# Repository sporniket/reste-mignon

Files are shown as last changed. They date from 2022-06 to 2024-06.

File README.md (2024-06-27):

# Sporniket's 'ReSTe mignon'

> [WARNING] Please read carefully this note before using this project. It contains important facts.

Content

1. What is **Sporniket's 'ReSTe mignon'**, and when to use it ?
2. What should you know before using **Sporniket's 'ReSTe mignon'** ?
3. How to use **Sporniket's 'ReSTe mignon'** ?
4. Known issues
5. Miscellanous

## 1. What is **Sporniket's 'ReSTe mignon'**, and when to use it ?

**Sporniket's 'ReSTe mignon'** is a _RE_-make of the computer known as 'Atari _STe_', on a B5-sized (250×175 mm) PCB. Smaller, so 'cute', hence '_mignon_'.

This is a project made with [Kicad](https://www.kicad.org/). I started this work [from the conversion of the original Atari STe schematics](https://github.com/sporniket/kicad-conversions--atari-ste-motherboard--c300780-001).

### Licence

**Sporniket's 'ReSTe mignon'** is marked with CC0 1.0 Universal. To view a copy of this license, visit http://creativecommons.org/publicdomain/zero/1.0

**Sporniket's 'ReSTe mignon'** is distributed in the hope that it will be useful, but WITHOUT ANY WARRANTY; without even the implied warranty of MERCHANTABILITY or FITNESS FOR A PARTICULAR PURPOSE.

### Releases notes

#### extension-cpu-68k-plcc68--v1.0.0-beta.1

First beta implemantion of the extension board holding the CPU in a PLCC68 package. This implements the [extension port for CPU and Blitter](README-extension-port-cpu-and-blitter.md)

#### mk0-0.1-schematic / 2022-06-08

The first complete schematics of the mark0 milestone, starting [from the conversion of the original Atari STe schematics](https://github.com/sporniket/kicad-conversions--atari-ste-motherboard--c300780-001).

  * Added DIP-64 CPU port extension
  * Removed T-filters
  * Deleted circuitry related to PAL/NTSC and modulator
  * Resolves #1 : Use 4-resistor packs wherever it is possible
  * Resolves #2 : apply the pull-up fix to data and address bus
  * Resolves #3 : Apply the DMA Pull up fix on databus
  * Resolves #4 : Apply the 1772 pull-up fix
  * Resolves #6 : Apply the reset fix
  * Resolves #5 : Apply the fix for the video ghosting
  * Resolves #7 : Assign SMD footprints to resistors pack
  * Resolves #8 : Assign 1206 hand-solder footprints to non polarized capacitors
  * Resolves #9 : Assign radial THT footprints to polarized capacitors
  * Resolves #10 : Remove the C103
  * Resolves #11 : Use the reference 'FB?' for the ferrite beads
  * Resolves #12 : Use the reference 'CP?' for polarized capacitors
  * Resolves #13 : assign 1206 hand-solder footprints to resistors
  * Resolves #14 : assign smd footprints for ferrite beads
  * Resolves #15 : assign smd footprints to the inductors
  * Resolves #16 : assign smd footprints to diodes
  * Resolves #17 : assign smd footprints to transistors
  * Resolves #18 : Apply the LMC mixer fix
  * Fixes #19 : Reinstate the external blitter for the mark 0 version
  * Resolves #20 : Replace polarized capacitors CP101 and CP536 by unpolarized ones
  * Resolves #21 : Change Q400 to Q405 from 2N3904 to MMBT3904
  * Resolves #22 : Change Q500 from LM78L82 to UA78L08 -- add bypass capacitor on input
  * Resolves #23 : Add internal ACSI port
  * Resolves #24 : Add an internal port to make easier to plug a RGB2HDMI
  * Fixes #28 : [BUG] Incomplete restoration of the blitter

## 2. What should you know before using **Sporniket's 'ReSTe mignon'** ?

**Sporniket's 'ReSTe mignon'** is made using [Kicad](https://www.kicad.org/).

The git repository use several submodules that one has to fetch in order to get the symbols, footprint and 3dmodels. One submodule requires [python3](https://www.python.org) and [GNU make](https://www.gnu.org/software/make/) to generate the libraries of symbols for integrated circuits.

> Do not use **Sporniket's 'ReSTe mignon'** if this project is not suitable for your project.

## 3. How to use **Sporniket's 'ReSTe mignon'** ?

### From sources

To get the latest available models, one must clone the git repository **and the submodules**. Then some modules needs a build step to generate its libraries.

	git clone --recurse-submodules https://github.com/sporniket/reste-mignon.git
	cd reste-mignon/kicad-symbols-generated
	make

Then, open the project in Kicad.

### From github releases

A github **schematic only** release (with `schematics` in the release tag and name) will provide a PDF of the schematics

A github **regular** release will provide :

* A standalone Kicad project (all custom libraries included and ready to use)
* A PDF of the schematics
* A PDF of the silkscreen
* If applicable, a Gerber for boardmanufacturer. Some details may have been adapted for a specific manufacturer.
* If applicable, a BOM, and pick an place files, likely for a specific manufacturer too.

## 4. Known issues
See the [project issues](https://github.com/sporniket/reste-mignon/issues) page.

## 5. Miscellanous

### Report issues
Use the [project issues](https://github.com/sporniket/reste-mignon/issues) page.

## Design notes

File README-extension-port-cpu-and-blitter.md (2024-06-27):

# Extension port for the CPU and Blitter

## Context

In order to reach the target dimension (given _surface_), it will be acceptable to _stack_ elements vertically.

The following specifications define an extension port that will allow to stack the CPU, and the blitter for setups that require it (namely, with a MCU without integrated blitter). Both will be stacked over the MCU.

## Physical layout

The overall goal is to have : 

* The biggest square with an side length rounded to 50 mils, that fits a 10×10cm square.
* Two head 100mils pitched header connectors, each 2 rows of different number of contacts, vertically oriented, put on a diagonally opposite corners of the square. 
  * **Connector A** will be on the north of the west side.
  * **Connector B** will be on the south of the east side. 
  * When one card is plugged on the main board or another card, the connector casing are flush with the borders
  
Which gives : 

* A square with a side of 3900mils/99.06mm
* From the North-West corner, pin #1 of connector A will be at coordinate (50,50) mils
* From pin #1 of connector A, pin #1 of connector B will be at coordinate (3700, 2300) mils

On the mainboard, the GST MCU will be oriented 90° clock-side, in other words, the GST MCU's North (pin #1 to the north-west) points toward the East of the extension port.

On the blitter extension, the North of the blitter (pin #1 to the north)  will points toward the South of the extension port.

On the PLCC CPU extension, the North of the CPU (pin #1 to the north) will points toward the East of the extension port.

On the DIP CPU extension, the North of the CPU (great axes of the DIP chip along North/South, pin #1 to the north) will points toward the North of the extension port

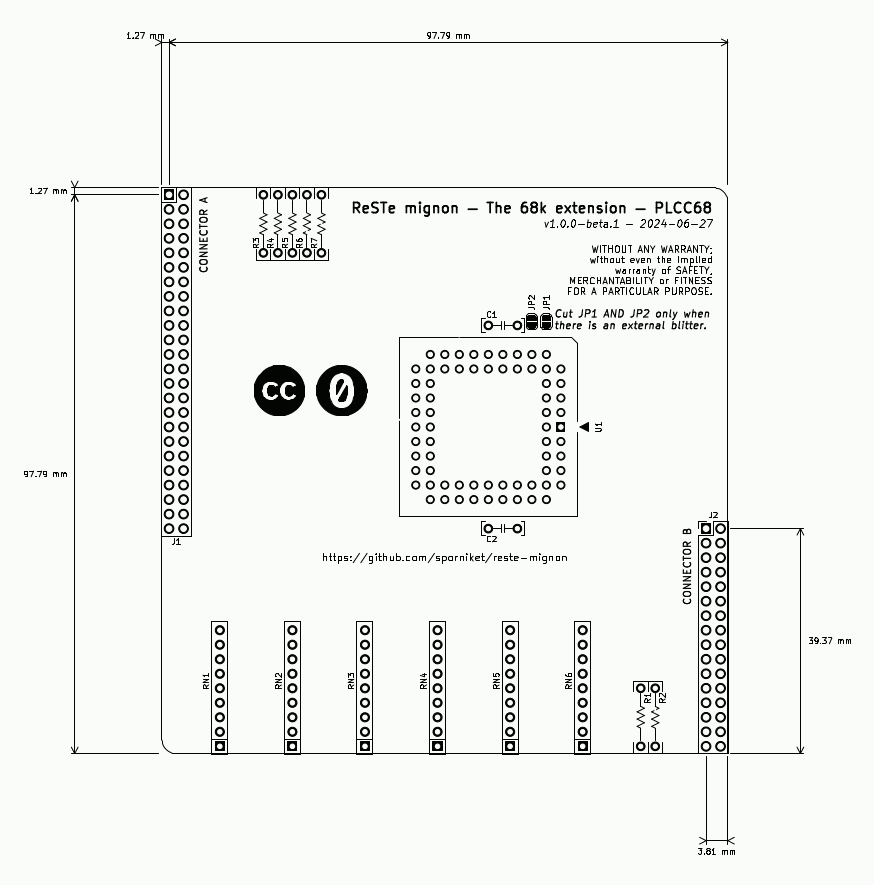
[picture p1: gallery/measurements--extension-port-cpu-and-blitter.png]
An actual extension pcb as a map of the extension port with measurements


## Connector specifications

The following pin assignments have been devised to minimize routing to the MCU, hopefully.

Pin numbers are assigned as follow :

* Connector seen from above, vertically oriented : the two rows are vertical, columns are horizontal.
* From left to right, columns by columns

Signals named prefixed by `BLT.` should target the blitter. Signals prefixed by `68.` should target the CPU.

### Connector A

| Pin | Signal | | Pin | Signal |
|---|---|---|---|---|
|1|`GND`| |2|`CLK`|
|3|`BERR`| |4|`GND`|
|5|`VPA`| |6|`VMA`|
|7|`BLT.BG`| |8|`BLT.BGACK`|
|9|`GND`| |10|`BR`|
|11|`IPL1`| |12|`IPL0`|
|13|`FC2`| |14|`IPL2`|
|15|`FC1`| |16|`GND`|
|17|`A23`| |18|`FC0`|
|19|`A21`| |20|`A22`|
|21|`GND`| |22|`A20`|
|23|`A18`| |24|`A19`|
|25|`A16`| |26|`A17`|
|27|`A15`| |28|`GND`|
|29|`A13`| |30|`A14`|
|31|`A11`| |32|`A12`|
|33|`GND`| |34|`A10`|
|35|`A8`| |36|`A9`|
|37|`A6`| |38|`A7`|
|39|`BLT.INT`| |40|`GND`|
|41|`A4`| |42|`A5`|
|43|`A2`| |44|`A3`|
|45|`GND`| |46|`A1`|
|47|`E`| |48|`GND`|

### Connector B

| Pin | Signal | | Pin | Signal |
|---|---|---|---|---|
|1|`D1`| |2|`D0`|
|3|`D2`| |4|`GND`|
|5|`D4`| |6|`D3`|
|7|`D6`| |8|`D5`|
|9|`GND`| |10|`D7`|
|11|`D9`| |12|`D8`|
|13|`D11`| |14|`D10`|
|15|`D12`| |16|`GND`|
|17|`D14`| |18|`D13`|
|19|`DTACK`| |20|`D15`|
|21|`GND`| |22|`R/W`|
|23|`UDS`| |24|`LDS`|
|25|`RESET`| |26|`AS`|
|27|`HALT`| |28|`GND`|
|29|`68.BG`| |30|`68.BGACK`|
|31|`VCC`| |32|`VCC`|

## Usages

### Main board

The extension port is placed around the GST MCU, so that the GST MCU will be oriented 90° clock-side, in other words, the GST MCU's North (pin #1 to the north-west) points toward the East of the extension port.

All the signal from the extension port, except `68.BGACK` and `68.BG` (connector B, pins #29 and #30), are wired to the MCU.

### Blitter extension

The extension port is placed around the blitter, so that the North of the blitter (pin #1 to the north)  will points toward the South of the extension port.

All relevant signals are wired to the blitter, espectially `68.BGACK` and `68.BG` (connector B, pins #29 and #30).

### CPU PLCC extension 

The extension port is placed around the PLCC CPU, so that the North of the CPU (pin #1 to the north) will points toward the East of the extension port.

All relevant signals are wired to the blitter, espectially `68.BGACK` and `68.BG` (connector B, pins #29 and #30).

A configuration system (jumpers, solder blobs, etc...) allows to connect to `BLT.BG` and `BLT.BGACK` (connector A, pins #7 and #8) in addition to `68.BGACK` and `68.BG`.

The CPU extension also implement the pull-ups on the various relevant signals.

### CPU DIP extension

The extension port is placed around the DIP CPU, so that the North of the CPU (great axes of the DIP chip along North/South, pin #1 to the north) will points toward the North of the extension port.

All relevant signals are wired to the blitter, espectially `68.BGACK` and `68.BG` (connector B, pins #29 and #30).

A configuration system (jumpers, solder blobs, etc...) allow to connect to `BLT.BG` and `BLT.BGACK` (connector A, pins #7 and #8) in addition to `68.BGACK` and `68.BG`.

The CPU extension also implement the pull-ups on the various relevant signals.

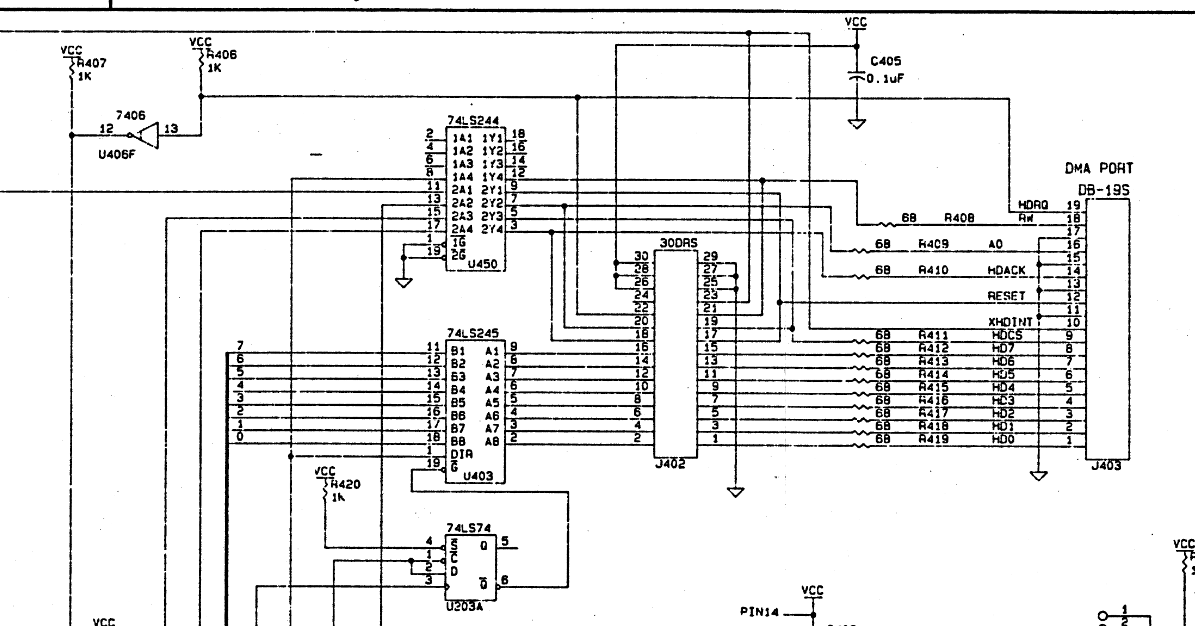
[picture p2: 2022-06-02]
references/MEGA_STE__ACSI_internal_connector.png

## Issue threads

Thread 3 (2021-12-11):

Apply the DMA Pull up fix on databus

sporniket, 2021-12-11:
See :

* https://www.exxoshost.co.uk/forum/viewtopic.php?f=17&t=1417
* https://www.exxoshost.co.uk/forum/viewtopic.php?f=23&t=1546&p=17513#p17513

Closed 2022-02-09.

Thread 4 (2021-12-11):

Apply the 1772 pull-up fix

sporniket, 2021-12-11:
See https://www.exxoshost.co.uk/forum/viewtopic.php?f=17&t=1395

sporniket, 2022-02-09:
Maybe leave this one to an optionnal board, as it depends off the drive actually connected ?

sporniket, 2022-02-10:
I will assume that there are more non-Atari drive than original drives, hence more probably needed.

Closed 2022-02-10.

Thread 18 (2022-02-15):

Apply the LMC mixer fix

sporniket, 2022-02-15:
See original description : http://atari.8bitchip.info/STEamFix.html

See another picture of the fix at the bottom of : https://www.exxoshost.co.uk/atari/last/STEDACFIX/index.htm

And another one in this thread : https://www.exxoshost.co.uk/forum/viewtopic.php?f=29&t=5119#p79553

Closed 2022-02-15.

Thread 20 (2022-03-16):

Replace polarized capacitors CP101 and CP536 by unpolarized ones

sporniket, 2022-03-16:
CP101 is 0.01uF ; CP536 is 0.1uF ; small enough to be replaced by MLCC capacitors.

CP101 &rarr; C101, assigned MLCC 1206 footprint
CP536 &rarr; C536, assigned MLCC 1206 footprint

Closed 2022-03-16.

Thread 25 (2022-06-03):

Add a video VGA port with a switch between color/monochrome mode

sporniket, 2022-06-03:
The VGA will route the analog video signal.

To switch between mono/rgb mode, a triple analog 2:1 mux is required, like SN74LV4053A. 4 trimpot are also require to setup the appropriate level/impedance for the vga monitor (to be checked).

Something along that :

* Red &rarr; trimpot_red &rarr; mux_1_a
* Green &rarr; trimpot_green &rarr; mux_2_a
* Blue &rarr; trimpot_blue &rarr; mux_3_a
* Mono &rarr; trimpot_mono &rarr; mux_1_b + mux_2_b + mux_3_b
* GND &rarr; switch &rarr; mux_ab_sel + pull_up + mono_detect **will force mono, even for the legacy connector**

sporniket, 2022-06-03:
Clearly out of scope for mark0. There is already plenty of adaptor to plug to a VGA monitor

Closed 2022-06-03.

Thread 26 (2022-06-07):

[EPIC] Allow an USB host to see the computer as an USB device

sporniket, 2022-06-07:
# Ideal Case : Serial and Parallel port

## Content

* an USB Hub IC (e.g. like the [TI TUSB2036 2 or 3 ports](https://www.ti.com/lit/ds/symlink/tusb2036.pdf))
* a power distribution IC (e.g. like the [TI TPS2044/TPS2054](https://www.ti.com/lit/ds/symlink/tps2054.pdf))
* a USB to Serial controller (WCH(Jiangsu Qin Heng) [CH340B](https://datasheet.lcsc.com/lcsc/2008191806_WCH-Jiangsu-Qin-Heng-CH340B_C81010.pdf) or [CH340T](https://datasheet.lcsc.com/lcsc/2008191806_WCH-Jiangsu-Qin-Heng-CH340T_C8689.pdf), the 'B' version needs an external 12MHz oscillator)
* a USB to Parallel port controller ([WCH(Jiangsu Qin Heng) CH340S](https://datasheet.lcsc.com/lcsc/2008191734_WCH-Jiangsu-Qin-Heng-CH340S_C109467.pdf) with external 12MHz oscillator)

The USB Hub IC and the power distribution IC are connected to the USB port (mini USB-B, or micro USB-C if unavailable, or mini USB-C if unavailable).

The '340 ICs are connected to the Hub and the power distribution ICs ; Serial is device 1, Parallel is device 2.

Level shifters are not needed

## Wiring to the ST

The pins listed are from the ST point of view. The wiring to the controllers ICs must be devised (e.g. like a [null modem](https://en.wikipedia.org/wiki/Null_modem) wiring to the Serial, and cross _busy_ and _strobe_ for Parallel)

### Serial

MC68901 :

* 8 (TX)
* 9 (RX)
* 23 (CD)
* 24 (CTS)
* 16 (RI)

YM2149

* 17 (DIR)
* 18 (RTS)

### Parallel

MC68901 :

* 22 (BUSY)

YM2149

* 6..13 (DATA[7..0], pin 6 is DATA[7], pin 13 is DATA[0])
* 16 (STROBE)

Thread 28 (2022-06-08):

[BUG] Incomplete restoration of the blitter

sporniket, 2022-06-08:
_Following #19_

* The DIP-64 socket /BG and /BGACK pins have not been reverted to `XCPUBG`/`XBGACK` resp.
* The blitter `XBGK` is pulled-up instead of `XBGACK`

Closed 2022-06-08.

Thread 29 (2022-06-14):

Redesign the reset circuit using a supervisory circuit

sporniket, 2022-06-14:
E.g. a supervisory circuit like the Microchip MPC100-450

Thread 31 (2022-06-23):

Provision mounting holes of the mother board to a chassis

sporniket, 2022-06-23:
The board targeting a B5 size (18x25 cm), there would be a grid of 3x4 = 12 mounting holes separated by around 8~9 cms

Those mounting holes will be compatible with [#6-32 UNC screws](https://en.wikipedia.org/wiki/Computer_case_screws##6-32_UNC_screw) and will be grounded

Closed 2022-07-13.

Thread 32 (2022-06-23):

Provision mounting hole for the 'dop' series of usb-c power delivery adapter

sporniket, 2022-06-23:
See

* dop-lite : https://github.com/sporniket/dop-lite /sporniket/dop-lite
* dop-regular : to do
* dop-heavy-duty : to do

Mounting holes : M2.5, like the Raspberry pi

* All the module will share the two holes around the usb port (2 holes).
* The lite module is smaller than the other one, thus will have 2 other holes that are not shared with the other units 2 other holes

&rArr; there will be 6 mounting holes. There will be enough clearance to avoid contact with metallic standoff and screws.

Closed 2022-07-13.

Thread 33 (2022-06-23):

Make the WD1772 pull-up fix optionnal

sporniket, 2022-06-23:
_Following #4_

As stated in [the initial fix description](https://exxosforum.co.uk/forum/viewtopic.php?f=17&t=1395), the fix may not be needed depending whether the actual device already has internal pull-ups or not.

Add 2 jumpers, one for the Write Data line (that require a pull-up strong enough for High Density support), and the other for the remaining lines. (see https://exxosforum.co.uk/forum/viewtopic.php?p=86993#p86993)

Closed 2022-06-23.

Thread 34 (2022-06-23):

Provision mounting holes for the Raspberry PI Zero (RGB2HDMI mod)

sporniket, 2022-06-23:
The Pi has 4 M2.5 holes

The holes will have a large clearance to avoid conduction.

Closed 2022-07-13.

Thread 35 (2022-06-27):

[mk0] allow to choose between the legacy reset circuit and a supervisory circuit

sporniket, 2022-06-27:
One could either build the legacy reset circuit, or replace it with a supervisory circuit in TO-92 package :

* Microchip MCP101-450DI/TO (push-pull output, no need for pull-up resistor)

# Microcontroller Supervisory Circuit with Push-Pull Output Active-High

> This datasheet is marked with CC0 1.0
> Universal. To view a copy of this license, visit
> http://creativecommons.org/publicdomain/zero/1.0

## Symbol

* Aliases : MCP101-D
* Reference : U
* Datasheet : https://ww1.microchip.com/downloads/aemDocuments/documents/APID/ProductDocuments/DataSheets/11187f.pdf
* Footprint : Package_TO_SOT_THT:TO-92L_Inline
* Pins layout : SIMM

## Pinout

|Pin|Name|Pin Type|Group|Comment|
|---|---|---|---|---|
|1|RST|O|OUT|Reset signal|
|2|VCC|PWR|||
|3|GND|GND|||

### Pin groups

|Group id|Rank|Comment|
|---|---|---|
|OUT|10|Output|

Closed 2022-07-13.

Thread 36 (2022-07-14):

Add a RJ11 Keyboard connector

sporniket, 2022-07-14:
To be able to connect a Mega ST(e)/TT keyboard

The filtering capacitors like in the MegaST will be added. No fuse.

Closed 2022-07-14.

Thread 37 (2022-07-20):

[mk0] Add a breakout connector for serial and parallel signal

sporniket, 2022-07-20:
> In order do experiments for #26

Make available one or two 2×X pin headers, 2.54mm pitch, connectors to have :
* Serial Rx/Tx at TTL levels &rArr; 2 signals
* Parallel data, strobe and busy &rArr; 10 signals

Either have :
* One 2×2 and one 2×10 pin headers connectors
* One 2×12 pin headers connector

A 24 wire ribbon cable will be used, with ground every other wire.

sporniket, 2022-10-28:
Used a 2x14 to add VCC

Closed 2022-10-28.

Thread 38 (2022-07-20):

[mk0] add a breakout connector for the MCU ROM[0..6]

sporniket, 2022-07-20:
> In preparation of #30

Located near the rom if possible, a 1×7 pin headers

sporniket, 2022-10-28:
put it near MCU, with 2x7 pin headers for grounding

Closed 2022-10-28.

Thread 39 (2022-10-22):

[mk0] Select THT power inductors for L203-L208

sporniket, 2022-10-22:
Hand soldering of SMD power coils will be troublesome given its larges contact areas.

* At least 220uH
* At least 750mA (the TL497A outputs at most 500mA)
* minimize the DC resistance.
* shielded is better
* radial, 2 leads spaced by 5mm, diameter < 15mm

Examples :
* ~Murata 12RS224C (1.1A, 290mΩ)~ (not selected, 4 leads)
* Sumida RCP1317NP-221L (1.6A, 278mΩ)
* Coilcraft RFS1113-224ME (1.65A, 295mΩ)
* Coilcraft RFS1317-224KL (2.05A, 239mΩ)

sporniket, 2022-10-22:
solved by 30bffc9

Closed 2022-10-22.

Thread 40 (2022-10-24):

Q500 : revert to TO-92 package and alternatives references

sporniket, 2022-10-24:
The SOT-89 will be difficult to hand-solder because of the exposed pad under the package.

Use the footprint "TO-92L_Inline_Wide"

Alternatives :
* STM L78L08
* Onsemi MC78L08
* Texas instrument UA78L08

Closed 2022-10-24.

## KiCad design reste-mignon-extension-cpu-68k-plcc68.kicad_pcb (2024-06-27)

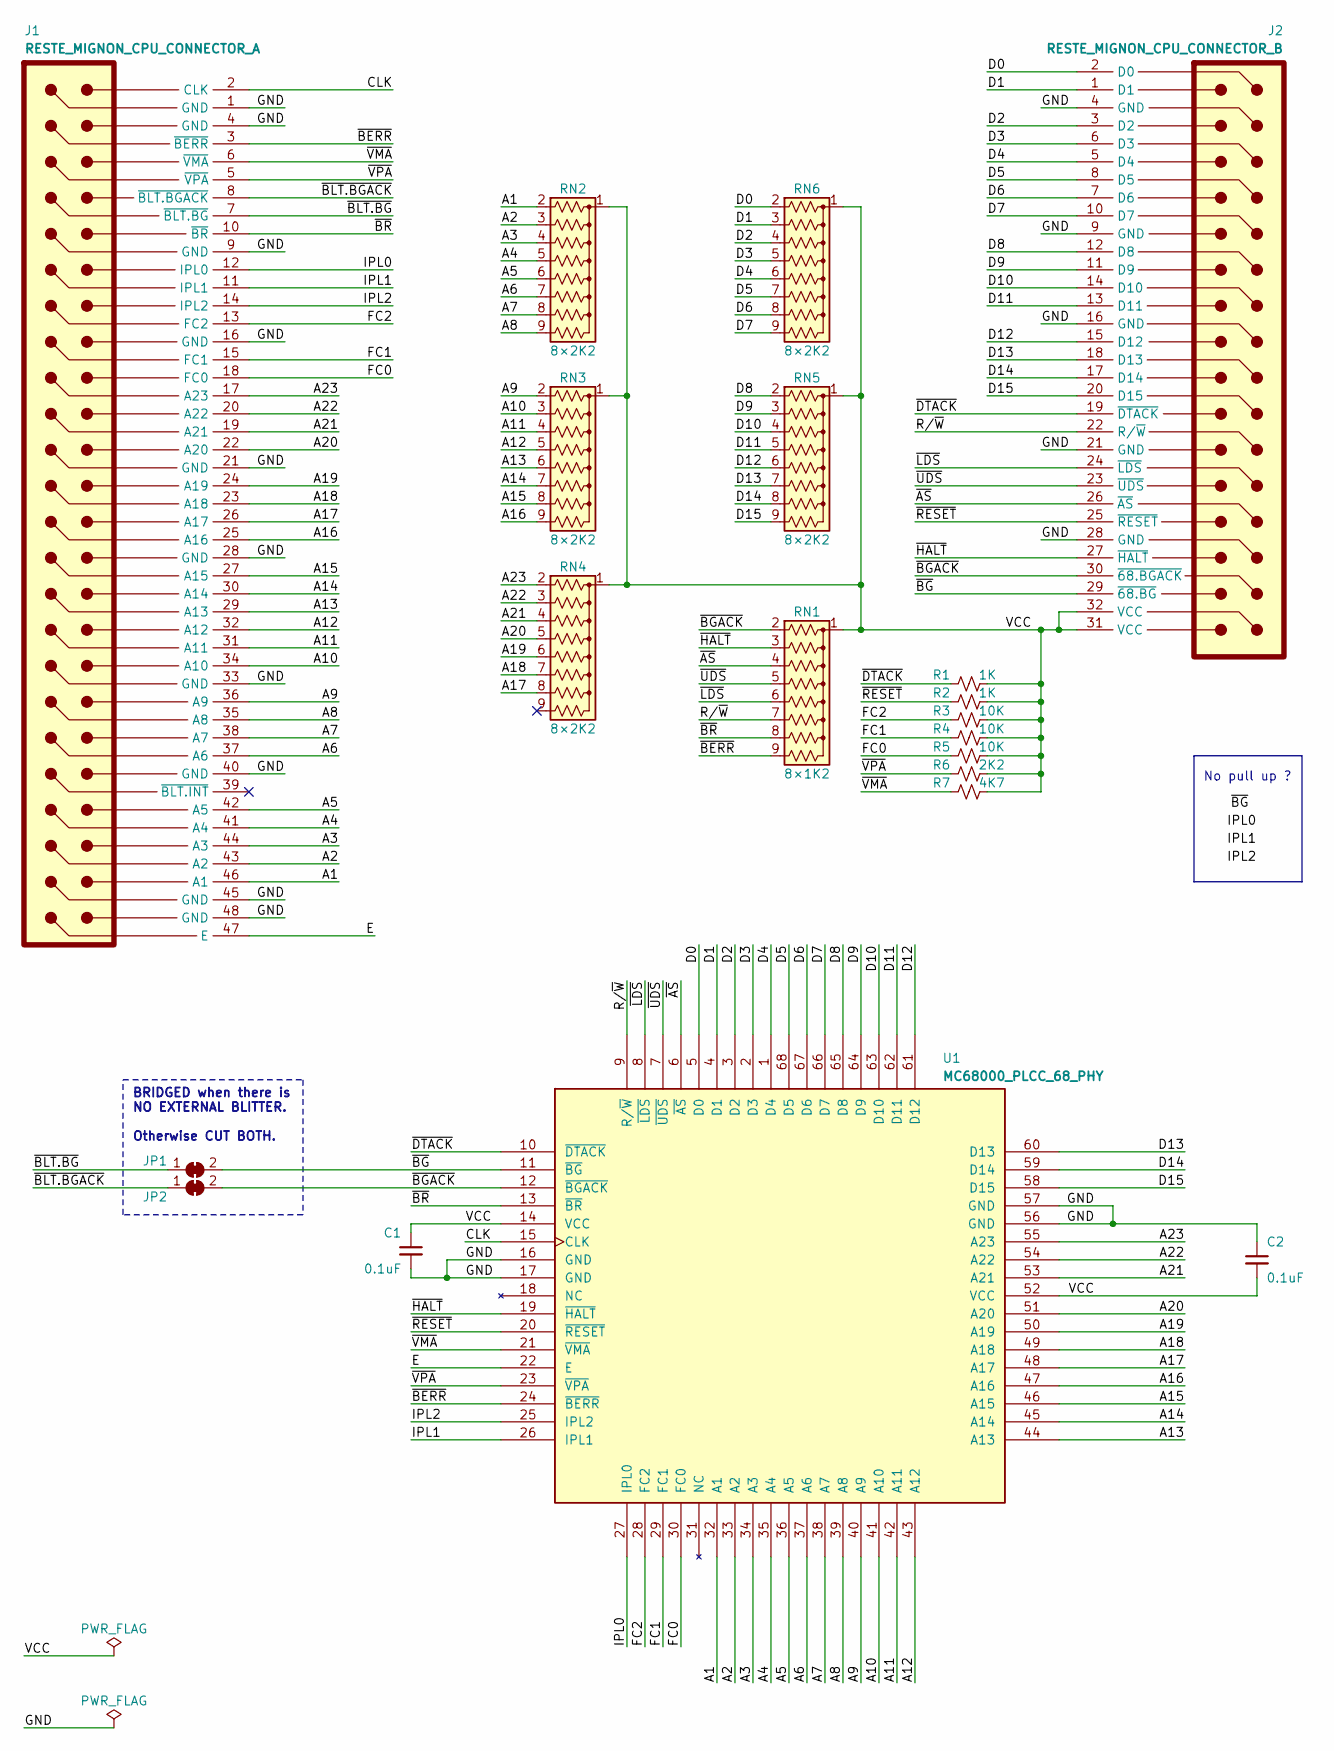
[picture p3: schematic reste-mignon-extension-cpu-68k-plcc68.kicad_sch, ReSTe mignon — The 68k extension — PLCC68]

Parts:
C1, C2: 0.1uF; Passive_THT_capacitor_mlcc_W2.54mm_L5.08mm
J1: RESTE_MIGNON_CPU_CONNECTOR_A; PinHeader_2x24_P2.54mm_Vertical
J2: RESTE_MIGNON_CPU_CONNECTOR_B; PinHeader_2x16_P2.54mm_Vertical
JP1, JP2: SolderJumper-2_P1.3mm_Bridged_RoundedPad1.0x1.5mm
R1, R2: 1K; Passive_THT_resistor_W2.54mm_L10.16mm
R3, R4, R5: 10K; Passive_THT_resistor_W2.54mm_L10.16mm
R6: 2K2; Passive_THT_resistor_W2.54mm_L10.16mm
R7: 4K7; Passive_THT_resistor_W2.54mm_L10.16mm
RN1: 8×1K2; R_Array_SIP9
RN2, RN3, RN4, RN5, RN6: 8×2K2; R_Array_SIP9
U1: MC68000_PLCC_68_PHY; PLCC-68_THT-Socket

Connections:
/A1: J1.46 (A1), RN2.2 (R1), U1.32 (A1)
/A2: J1.43 (A2), RN2.3 (R2), U1.33 (A2)
/A3: J1.44 (A3), RN2.4 (R3), U1.34 (A3)
/A4: J1.41 (A4), RN2.5 (R4), U1.35 (A4)
/A5: J1.42 (A5), RN2.6 (R5), U1.36 (A5)
/A6: J1.37 (A6), RN2.7 (R6), U1.37 (A6)
/A7: J1.38 (A7), RN2.8 (R7), U1.38 (A7)
/A8: J1.35 (A8), RN2.9 (R8), U1.39 (A8)
/A9: J1.36 (A9), RN3.2 (R1), U1.40 (A9)
/A10: J1.34 (A10), RN3.3 (R2), U1.41 (A10)
/A11: J1.31 (A11), RN3.4 (R3), U1.42 (A11)
/A12: J1.32 (A12), RN3.5 (R4), U1.43 (A12)
/A13: J1.29 (A13), RN3.6 (R5), U1.44 (A13)
/A14: J1.30 (A14), RN3.7 (R6), U1.45 (A14)
/A15: J1.27 (A15), RN3.8 (R7), U1.46 (A15)
/A16: J1.25 (A16), RN3.9 (R8), U1.47 (A16)
/A17: J1.26 (A17), RN4.8 (R7), U1.48 (A17)
/A18: J1.23 (A18), RN4.7 (R6), U1.49 (A18)
/A19: J1.24 (A19), RN4.6 (R5), U1.50 (A19)
/A20: J1.22 (A20), RN4.5 (R4), U1.51 (A20)
/A21: J1.19 (A21), RN4.4 (R3), U1.53 (A21)
/A22: J1.20 (A22), RN4.3 (R2), U1.54 (A22)
/A23: J1.17 (A23), RN4.2 (R1), U1.55 (A23)
/CLK: J1.2 (CLK), U1.15 (CLK)
/D0: J2.2 (D0), RN6.2 (R1), U1.5 (D0)
/D1: J2.1 (D1), RN6.3 (R2), U1.4 (D1)
/D2: J2.3 (D2), RN6.4 (R3), U1.3 (D2)
/D3: J2.6 (D3), RN6.5 (R4), U1.2 (D3)
/D4: J2.5 (D4), RN6.6 (R5), U1.1 (D4)
/D5: J2.8 (D5), RN6.7 (R6), U1.68 (D5)
/D6: J2.7 (D6), RN6.8 (R7), U1.67 (D6)
/D7: J2.10 (D7), RN6.9 (R8), U1.66 (D7)
/D8: J2.12 (D8), RN5.2 (R1), U1.65 (D8)
/D9: J2.11 (D9), RN5.3 (R2), U1.64 (D9)
/D10: J2.14 (D10), RN5.4 (R3), U1.63 (D10)
/D11: J2.13 (D11), RN5.5 (R4), U1.62 (D11)
/D12: J2.15 (D12), RN5.6 (R5), U1.61 (D12)
/D13: J2.18 (D13), RN5.7 (R6), U1.60 (D13)
/D14: J2.17 (D14), RN5.8 (R7), U1.59 (D14)
/D15: J2.20 (D15), RN5.9 (R8), U1.58 (D15)
/E: J1.47 (E), U1.22 (E)
/FC0: J1.18 (FC0), R5.1, U1.30 (FC0)
/FC1: J1.15 (FC1), R4.1, U1.29 (FC1)
/FC2: J1.13 (FC2), R3.1, U1.28 (FC2)
/GND: C1.2, C2.1, J1.1 (GND), J1.4 (GND), J1.9 (GND), J1.16 (GND), J1.21 (GND), J1.28 (GND), J1.33 (GND), J1.40 (GND), J1.45 (GND), J1.48 (GND), J2.4 (GND), J2.9 (GND), J2.16 (GND), J2.21 (GND), J2.28 (GND), U1.16 (GND), U1.17 (GND), U1.56 (GND), U1.57 (GND)
/IPL0: J1.12 (IPL0), U1.27 (IPL0)
/IPL1: J1.11 (IPL1), U1.26 (IPL1)
/IPL2: J1.14 (IPL2), U1.25 (IPL2)
/R/~W: J2.22 (R/~W), RN1.7 (R6), U1.9 (R/~W)
/VCC: C1.1, C2.2, J2.31 (VCC), J2.32 (VCC), R1.2, R2.2, R3.2, R4.2, R5.2, R6.2, R7.2, RN1.1 (common), RN2.1 (common), RN3.1 (common), RN4.1 (common), RN5.1 (common), RN6.1 (common), U1.14 (VCC), U1.52 (VCC)
/~AS: J2.26 (~AS), RN1.4 (R3), U1.6 (~AS)
/~BERR: J1.3 (~BERR), RN1.9 (R8), U1.24 (~BERR)
/~BGACK: J2.30 (~68.BGACK), JP2.2 (B), RN1.2 (R1), U1.12 (~BGACK)
/~BG: J2.29 (~68.BG), JP1.2 (B), U1.11 (~BG)
/~BLT.BGACK: J1.8 (~BLT.BGACK), JP2.1 (A)
/~BLT.BG: J1.7 (~BLT.BG), JP1.1 (A)
/~BR: J1.10 (~BR), RN1.8 (R7), U1.13 (~BR)
/~DTACK: J2.19 (~DTACK), R1.1, U1.10 (~DTACK)
/~HALT: J2.27 (~HALT), RN1.3 (R2), U1.19 (~HALT)
/~LDS: J2.24 (~LDS), RN1.6 (R5), U1.8 (~LDS)
/~RESET: J2.25 (~RESET), R2.1, U1.20 (~RESET)
/~UDS: J2.23 (~UDS), RN1.5 (R4), U1.7 (~UDS)
/~VMA: J1.6 (~VMA), R7.1, U1.21 (~VMA)
/~VPA: J1.5 (~VPA), R6.1, U1.23 (~VPA)

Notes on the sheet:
No pull up ?
BRIDGED when there is NO EXTERNAL BLITTER. Otherwise CUT BOTH.

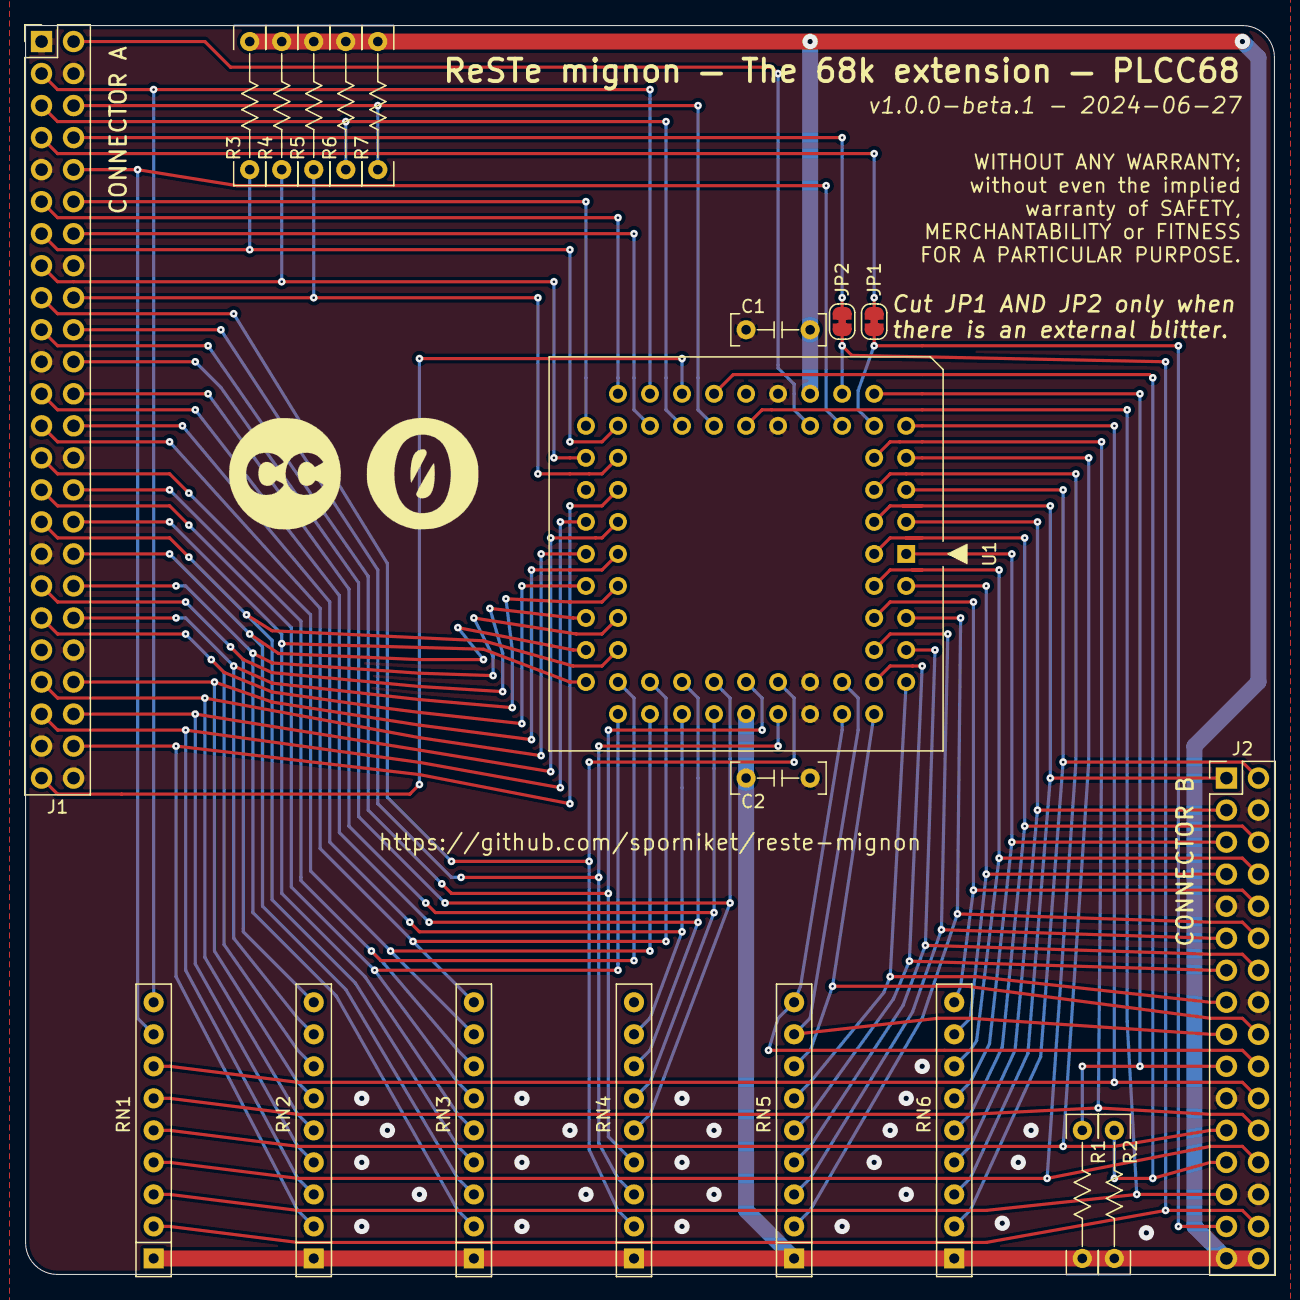
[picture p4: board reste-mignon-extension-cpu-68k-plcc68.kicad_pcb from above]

Board: 4 copper layers, 99.1 x 99.1 mm, 20 parts (0 on the bottom side), 64 nets.

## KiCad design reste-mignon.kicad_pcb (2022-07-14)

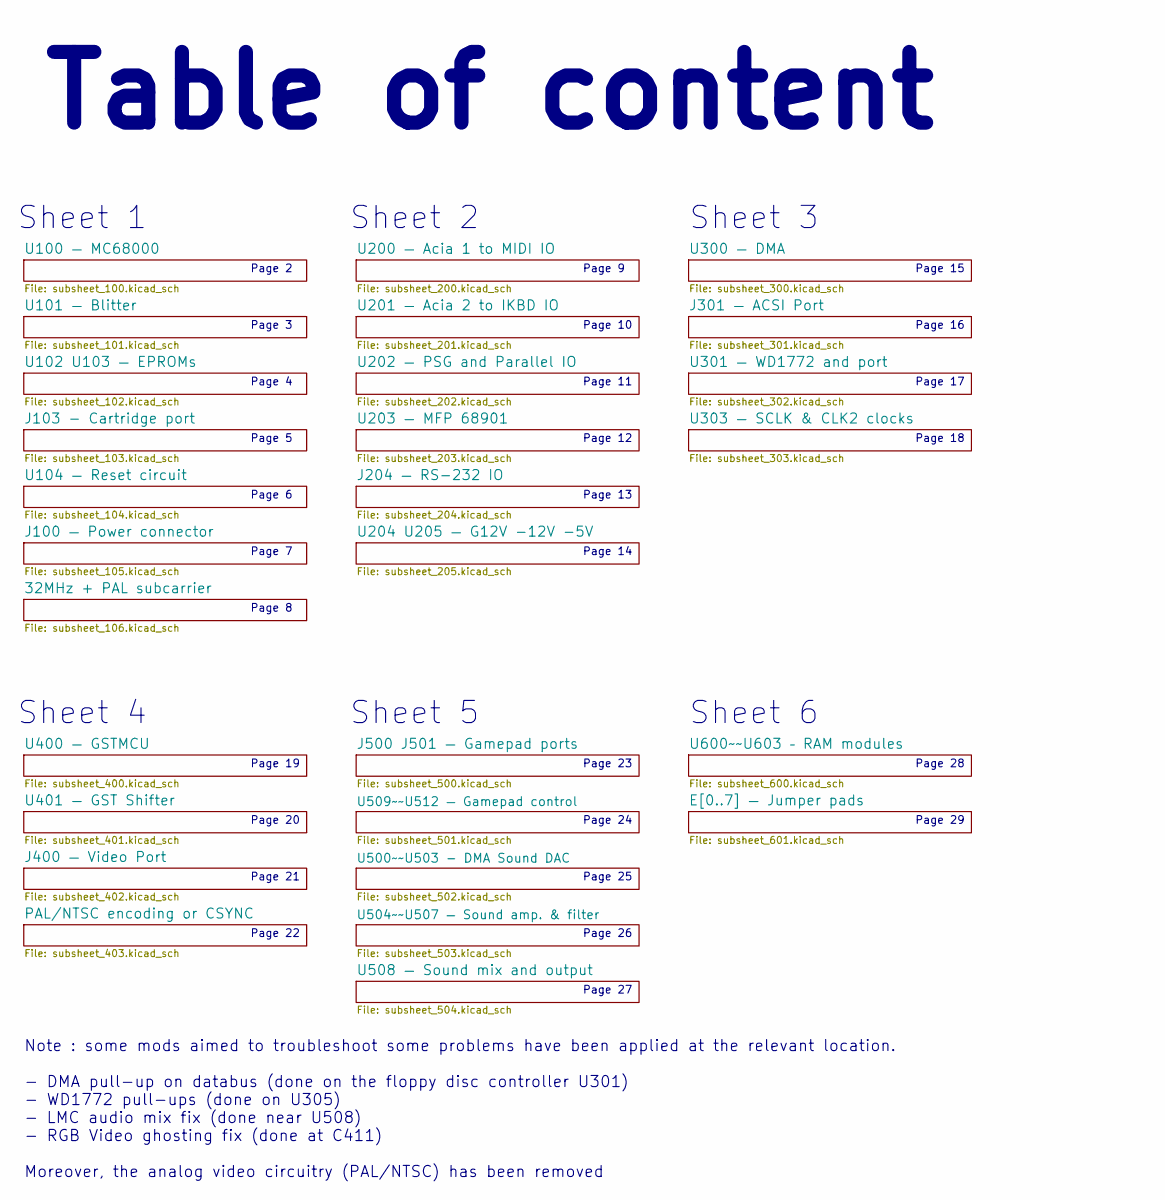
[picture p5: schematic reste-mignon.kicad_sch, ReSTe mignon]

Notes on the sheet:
Note : some mods aimed to troubleshoot some problems have been applied at the relevant location. - DMA pull-up on databus (done on the floppy disc controller U301) - WD1772 pull-ups (done on U305) - LMC audio mix fix (done near U508) - RGB Video ghosting fix (done at C411) Moreover, the analog vide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
Page 15
Page 14
Page 24
Page 25
Sheet 3
Page 10
Page 23
Page 9
Page 4
Page 13
Page 27
Page 20
Page 28
Page 6
Page 16
Page 2
Sheet 1
Sheet 4
Page 29
Page 11
Sheet 2
Page 26
Page 22
Page 17
Page 7
Sheet 5
Page 21
Page 12
Page 19
Page 18
Page 3
Table of content
Sheet 6
Page 8
Page 5

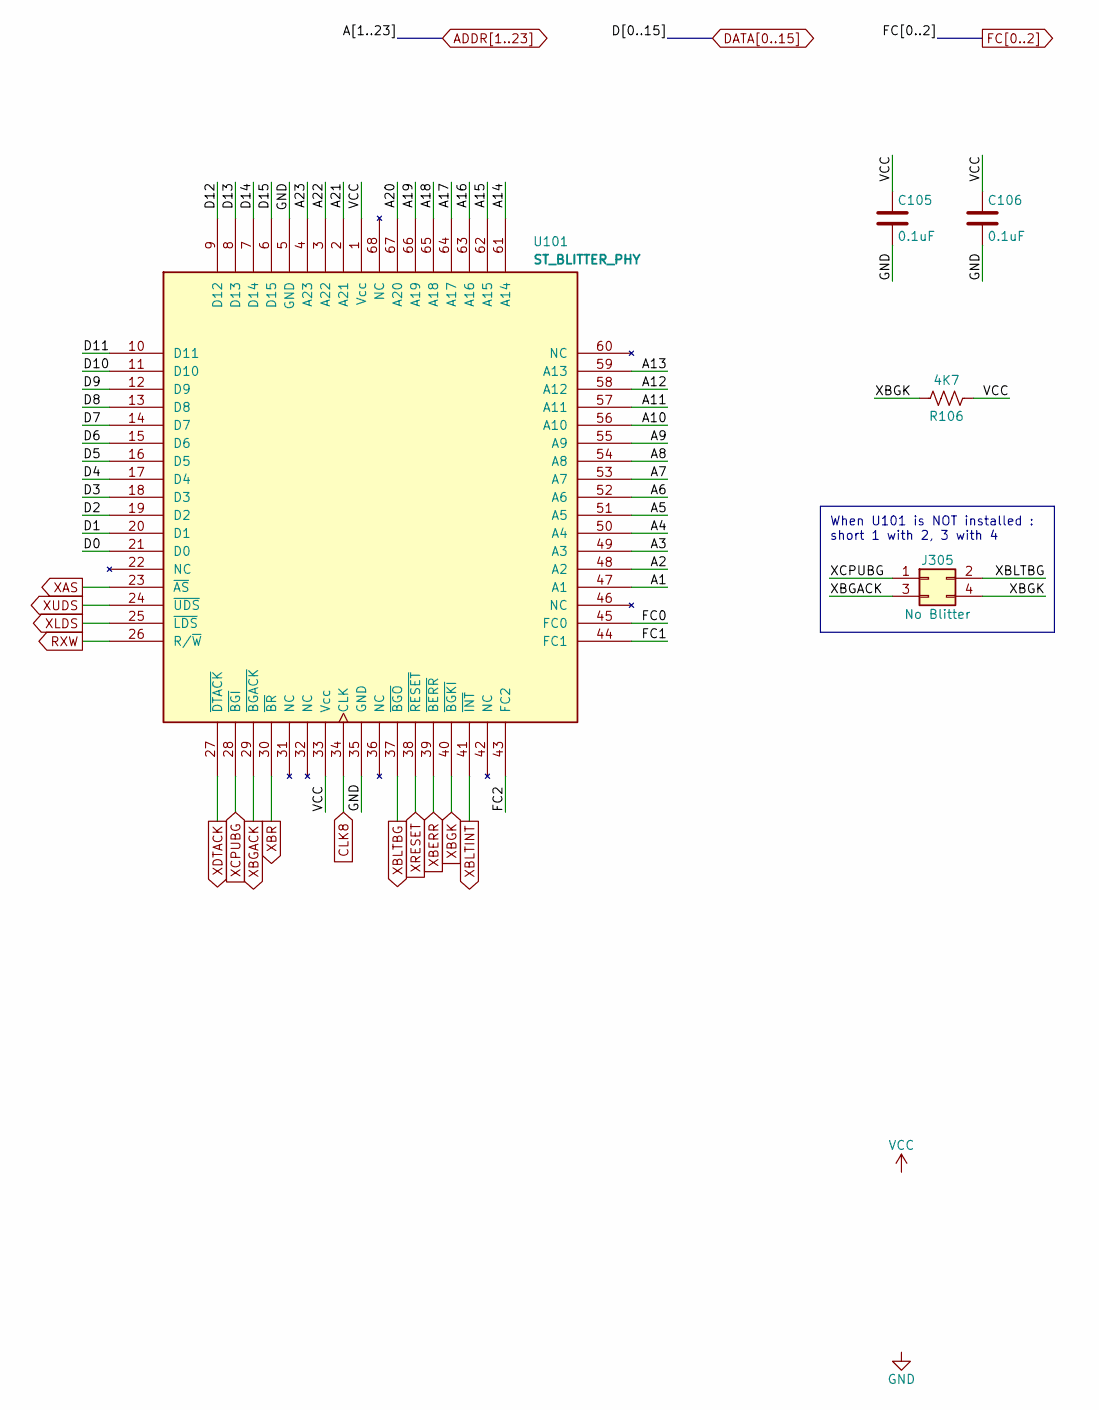
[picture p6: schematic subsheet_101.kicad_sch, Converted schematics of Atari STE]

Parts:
C105, C106: 0.1uF; C_1206_3216Metric_Pad1.33x1.80mm_HandSolder
J305: No Blitter; PinHeader_2x02_P2.54mm_Vertical
R106: 4K7; R_1206_3216Metric_Pad1.30x1.75mm_HandSolder
U101: ST_BLITTER_PHY; PLCC-68_THT-Socket

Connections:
ADDR22: U101.3 (A22); also elsewhere on the board
CLK8: U101.34 (CLK); also elsewhere on the board
DATA0: U101.21 (D0); also elsewhere on the board
DATA1: U101.20 (D1); also elsewhere on the board
DATA2: U101.19 (D2); also elsewhere on the board
DATA3: U101.18 (D3); also elsewhere on the board
DATA4: U101.17 (D4); also elsewhere on the board
DATA5: U101.16 (D5); also elsewhere on the board
DATA6: U101.15 (D6); also elsewhere on the board
DATA7: U101.14 (D7); also elsewhere on the board
DATA8: U101.13 (D8); also elsewhere on the board
DATA9: U101.12 (D9); also elsewhere on the board
DATA10: U101.11 (D10); also elsewhere on the board
DATA11: U101.10 (D11); also elsewhere on the board
DATA12: U101.9 (D12); also elsewhere on the board
DATA13: U101.8 (D13); also elsewhere on the board
DATA14: U101.7 (D14); also elsewhere on the board
DATA15: U101.6 (D15); also elsewhere on the board
FC0: U101.45 (FC0); also elsewhere on the board
FC1: U101.44 (FC1); also elsewhere on the board
FC2: U101.43 (FC2); also elsewhere on the board
GND: C105.2, C106.2, U101.5 (GND), U101.35 (GND); also elsewhere on the board
RXW: U101.26 (R/~W); also elsewhere on the board
XAS: U101.23 (~AS); also elsewhere on the board
XBGK: J305.4, R106.2, U101.40 (~BGKI); also elsewhere on the board
XBLTBG: J305.2, U101.37 (~BGO); also elsewhere on the board
XBLTINT: U101.41 (~INT); also elsewhere on the board
XCPUBG: J305.1, U101.28 (~BGI); also elsewhere on the board
XDTACK: U101.27 (~DTACK); also elsewhere on the board
XLDS: U101.25 (~LDS); also elsewhere on the board
XRESET: U101.38 (~RESET); also elsewhere on the board
XUDS: U101.24 (~UDS); also elsewhere on the board

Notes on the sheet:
When U101 is NOT installed : short 1 with 2, 3 with 4

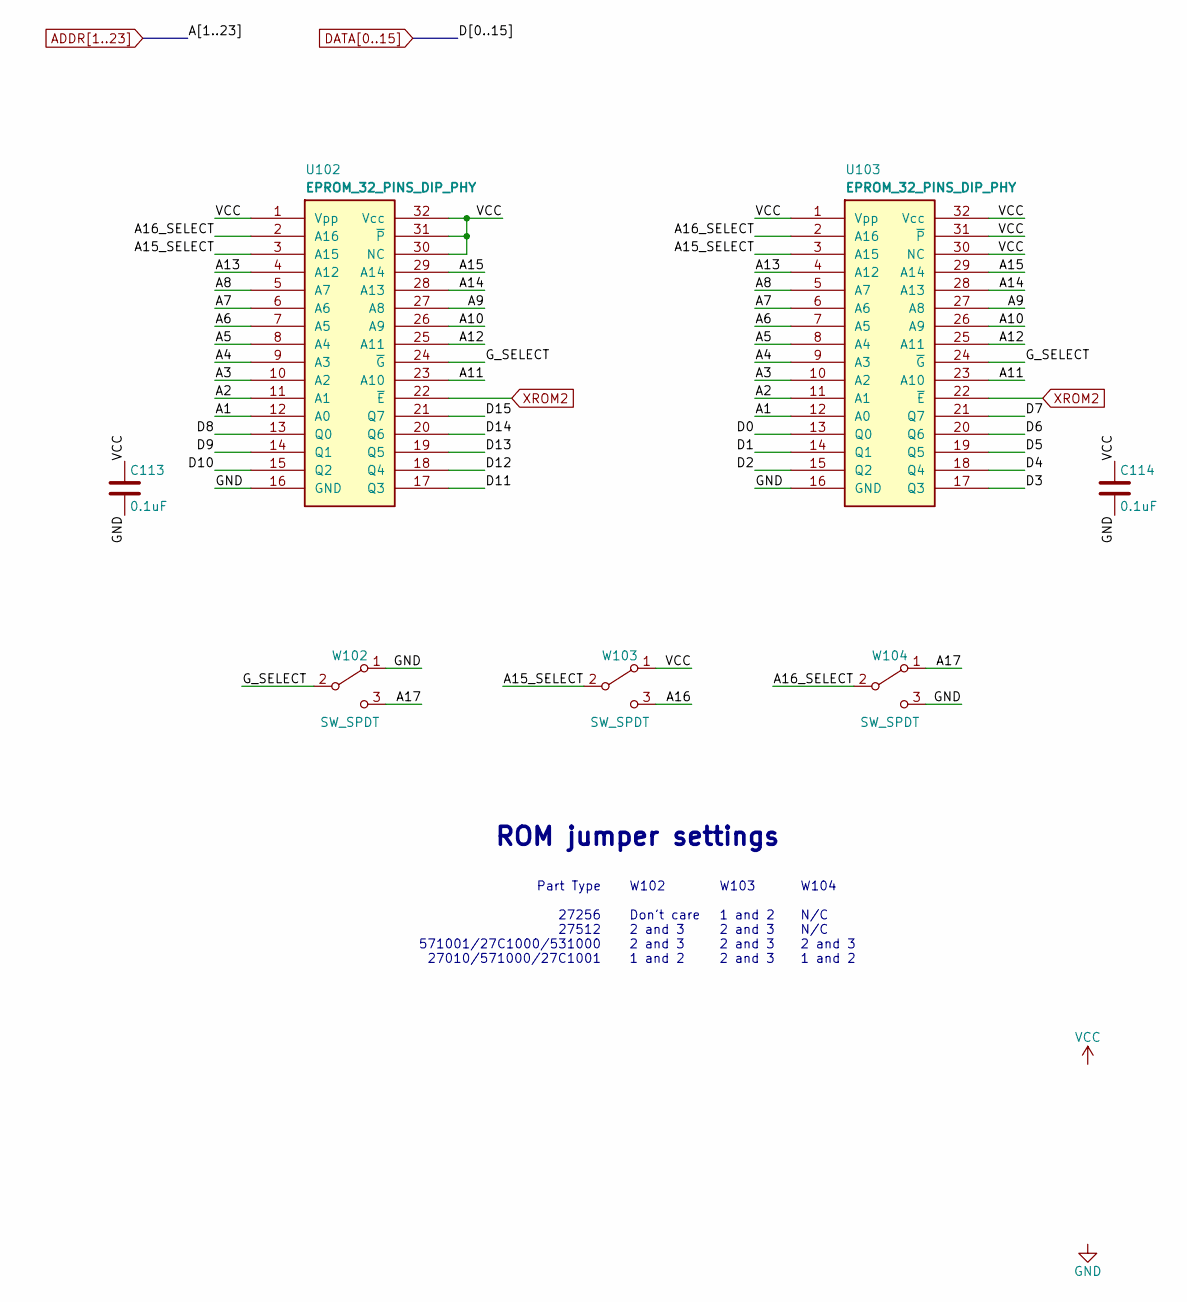
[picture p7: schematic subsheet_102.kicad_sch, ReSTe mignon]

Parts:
C113, C114: 0.1uF; C_1206_3216Metric_Pad1.33x1.80mm_HandSolder
U102, U103: EPROM_32_PINS_DIP_PHY; DIP-32_W15.24mm_LongPads
W102, W103, W104: SW_SPDT; PinHeader_1x03_P2.54mm_Vertical

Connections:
/U102 U103 — EPROMs/A15_SELECT: U102.3 (A15), U103.3 (A15), W103.2 (B)
/U102 U103 — EPROMs/A16_SELECT: U102.2 (A16), U103.2 (A16), W104.2 (B)
/U102 U103 — EPROMs/G_SELECT: U102.24 (~G), U103.24 (~G), W102.2 (B)
DATA0: U103.13 (Q0); also elsewhere on the board
DATA1: U103.14 (Q1); also elsewhere on the board
DATA2: U103.15 (Q2); also elsewhere on the board
DATA3: U103.17 (Q3); also elsewhere on the board
DATA4: U103.18 (Q4); also elsewhere on the board
DATA5: U103.19 (Q5); also elsewhere on the board
DATA6: U103.20 (Q6); also elsewhere on the board
DATA7: U103.21 (Q7); also elsewhere on the board
DATA8: U102.13 (Q0); also elsewhere on the board
DATA9: U102.14 (Q1); also elsewhere on the board
DATA10: U102.15 (Q2); also elsewhere on the board
DATA11: U102.17 (Q3); also elsewhere on the board
DATA12: U102.18 (Q4); also elsewhere on the board
DATA13: U102.19 (Q5); also elsewhere on the board
DATA14: U102.20 (Q6); also elsewhere on the board
DATA15: U102.21 (Q7); also elsewhere on the board
GND: C113.2, C114.2, U102.16 (GND), U103.16 (GND), W102.1 (A), W104.3 (C); also elsewhere on the board
XROM2: U102.22 (~E), U103.22 (~E); also elsewhere on the board

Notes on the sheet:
ROM jumper settings
W103 1 and 2 2 and 3 2 and 3 2 and 3
Part Type 27256 27512 571001/27C1000/531000 27010/571000/27C1001
W104 N/C N/C 2 and 3 1 and 2
W102 Don't care 2 and 3 2 and 3 1 and 2

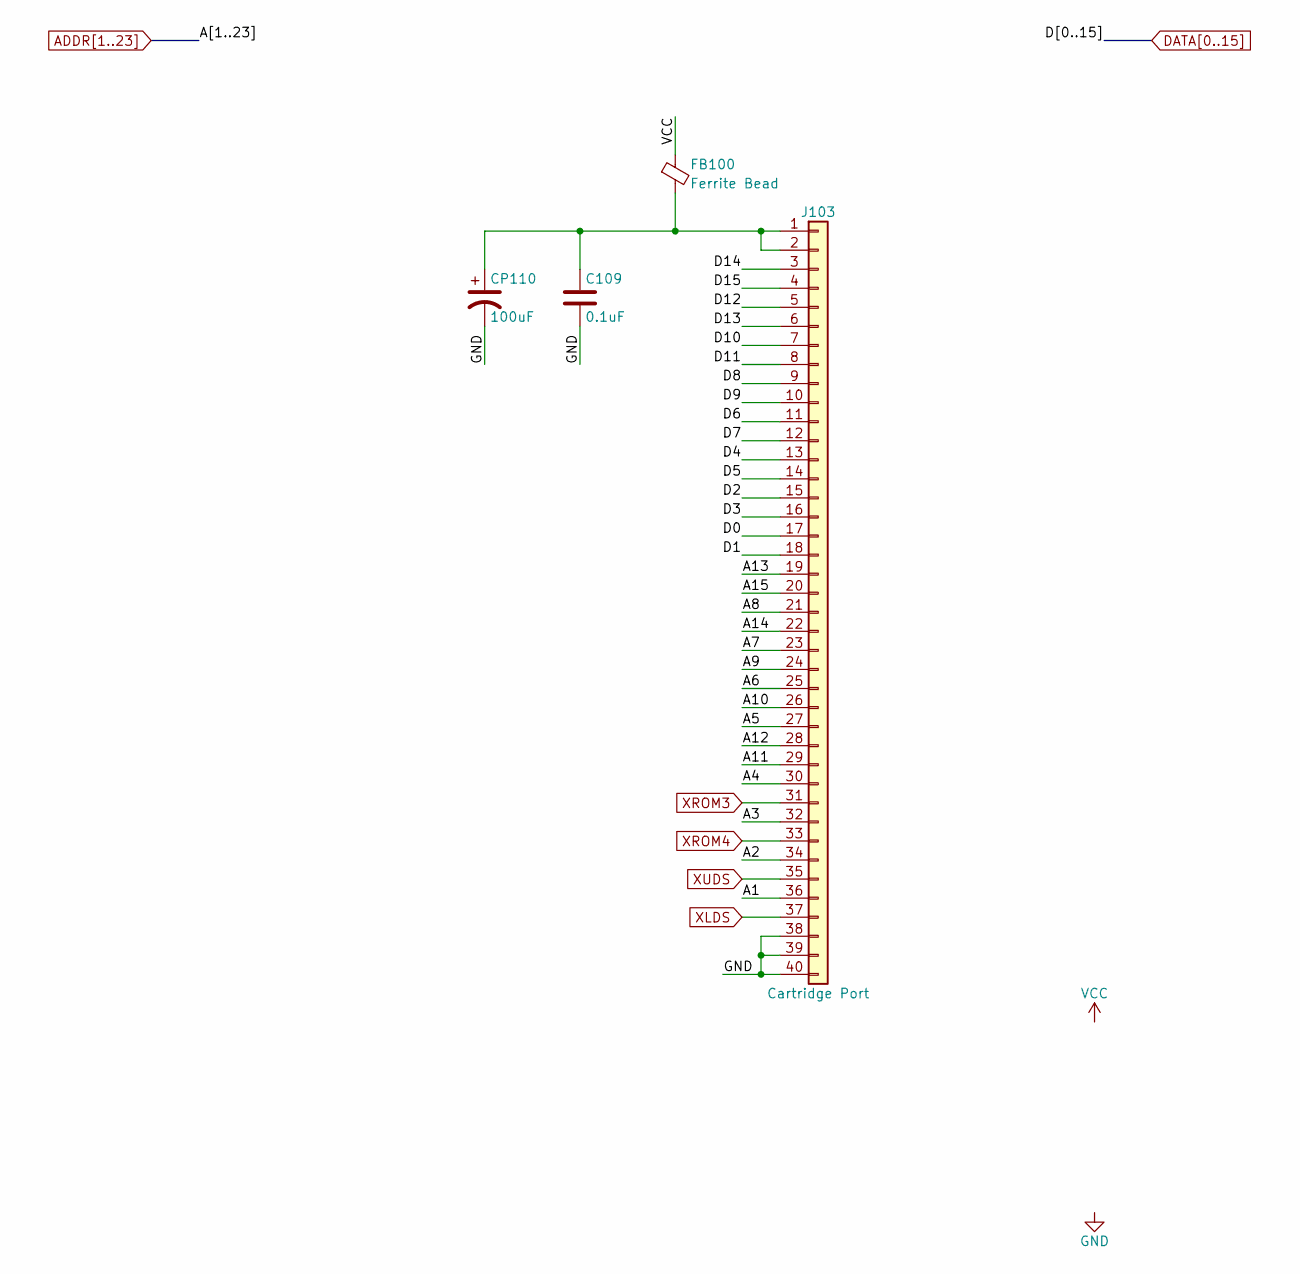
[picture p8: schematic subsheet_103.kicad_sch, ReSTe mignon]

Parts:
C109: 0.1uF; C_1206_3216Metric_Pad1.33x1.80mm_HandSolder
CP110: 100uF; C_Radial_D8.0mm_H11.5mm_P3.50mm
FB100: Ferrite Bead; L_1206_3216Metric_Pad1.22x1.90mm_HandSolder
J103: Cartridge Port; socket-edge-pcb_40p_P2.01mm

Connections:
DATA0: J103.17; also elsewhere on the board
DATA1: J103.18; also elsewhere on the board
DATA2: J103.15; also elsewhere on the board
DATA3: J103.16; also elsewhere on the board
DATA4: J103.13; also elsewhere on the board
DATA5: J103.14; also elsewhere on the board
DATA6: J103.11; also elsewhere on the board
DATA7: J103.12; also elsewhere on the board
DATA8: J103.9; also elsewhere on the board
DATA9: J103.10; also elsewhere on the board
DATA10: J103.7; also elsewhere on the board
DATA11: J103.8; also elsewhere on the board
DATA12: J103.5; also elsewhere on the board
DATA13: J103.6; also elsewhere on the board
DATA14: J103.3; also elsewhere on the board
DATA15: J103.4; also elsewhere on the board
GND: C109.2, CP110.2, J103.38, J103.39, J103.40; also elsewhere on the board
unnamed: C109.1, CP110.1, FB100.2, J103.1, J103.2
XLDS: J103.37; also elsewhere on the board
XROM3: J103.31; also elsewhere on the board
XROM4: J103.33; also elsewhere on the board
XUDS: J103.35; also elsewhere on the board

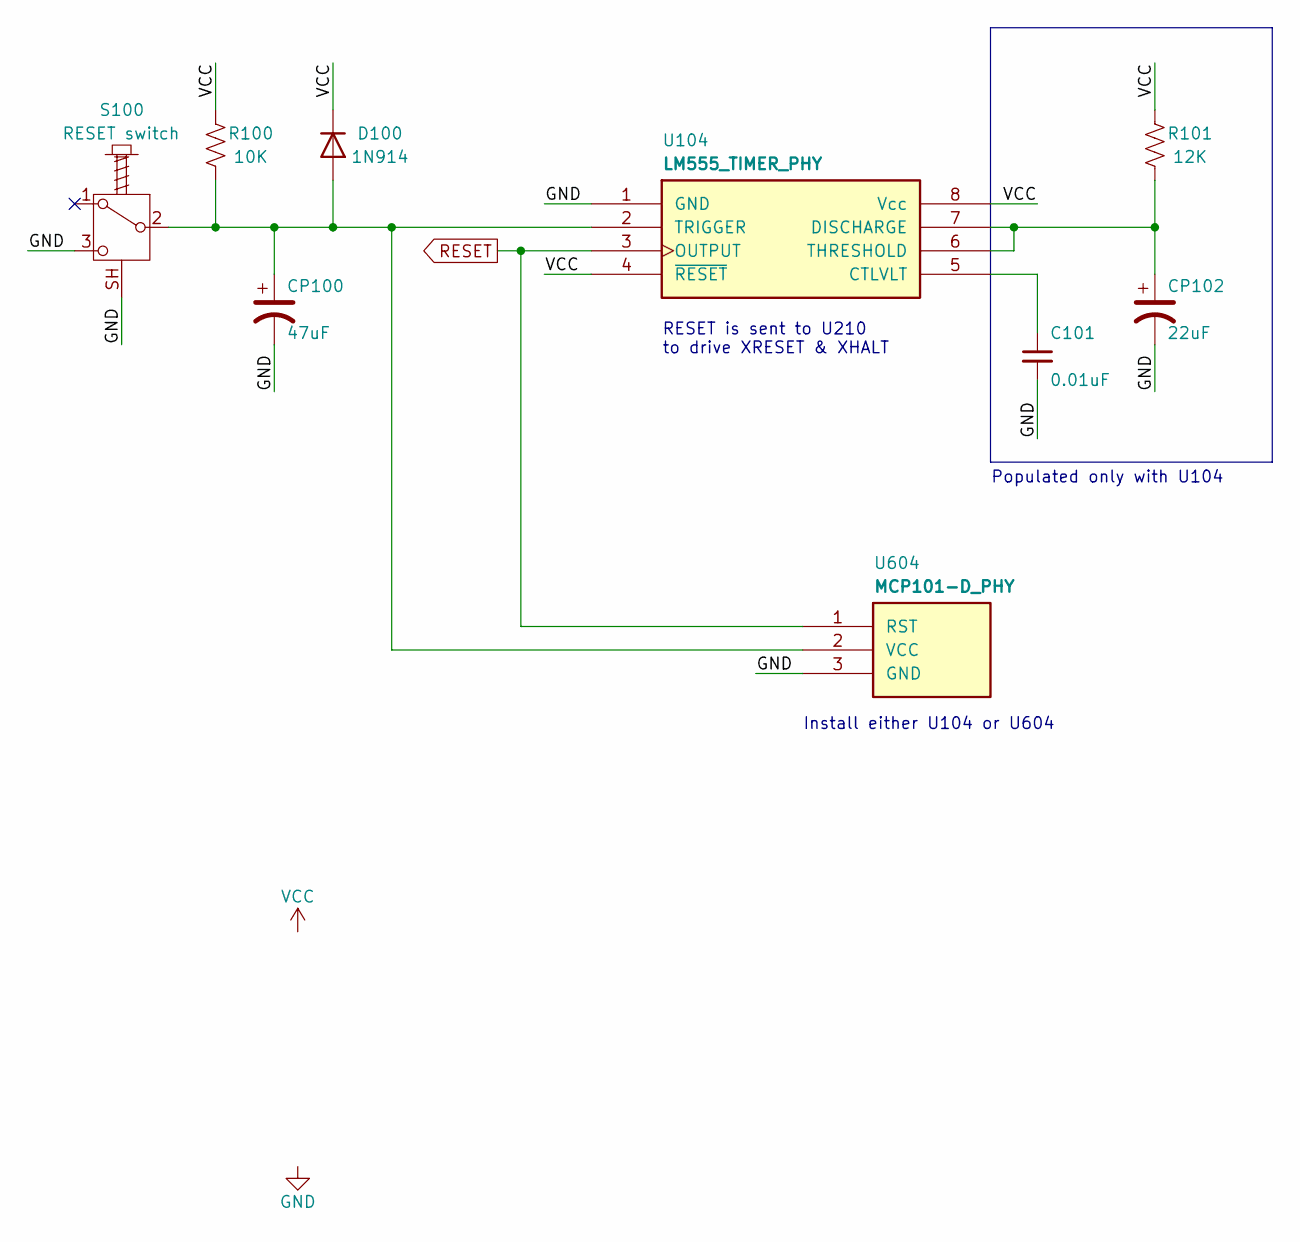
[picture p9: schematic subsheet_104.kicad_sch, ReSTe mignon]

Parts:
C101: 0.01uF; C_1206_3216Metric_Pad1.33x1.80mm_HandSolder
CP100: 47uF; C_Radial_D6.3mm_H11.0mm_P2.50mm
CP102: 22uF; C_Radial_D5.0mm_H11.0mm_P2.00mm
D100: 1N914; D_SOD-123F
R100: 10K; R_1206_3216Metric_Pad1.30x1.75mm_HandSolder
R101: 12K; R_1206_3216Metric_Pad1.30x1.75mm_HandSolder
S100: RESET switch; switch-spdt-momentary-action_Reset_pushbutton
U104: LM555_TIMER_PHY; DIP-8_W7.62mm_LongPads
U604: MCP101-D_PHY; TO-92L_Inline

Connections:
GND: C101.2, CP100.2, CP102.2, S100.3 (C), S100.SH (Shield), U104.1 (GND), U604.3 (GND); also elsewhere on the board
unnamed: C101.1, U104.5 (CTLVLT)
unnamed: CP100.1, D100.2 (A), R100.2, S100.2 (B), U104.2 (TRIGGER), U604.2 (VCC)
unnamed: CP102.1, R101.2, U104.6 (THRESHOLD), U104.7 (DISCHARGE)
RESET: U104.3 (OUTPUT), U604.1 (RST); also elsewhere on the board

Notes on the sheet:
Install either U104 or U604
Populated only with U104
RESET is sent to U210 to drive XRESET & XHALT

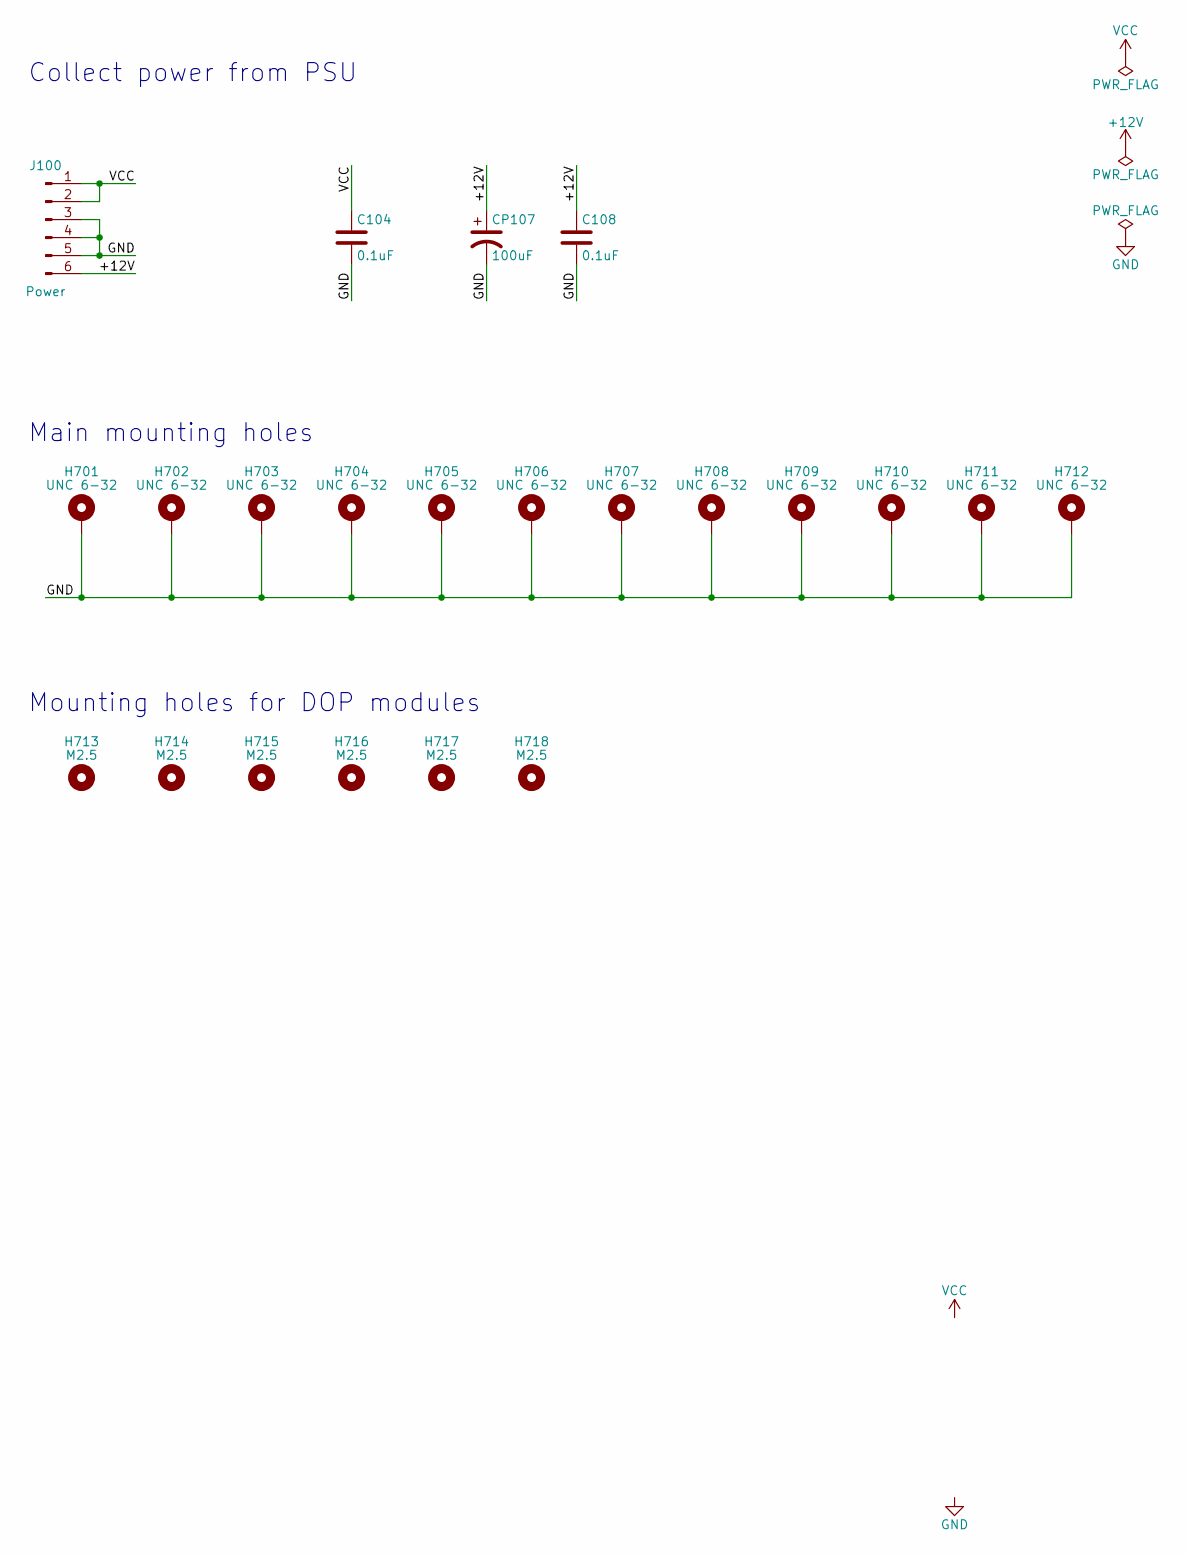
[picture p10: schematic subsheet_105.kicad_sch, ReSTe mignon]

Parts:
C104, C108: 0.1uF; C_1206_3216Metric_Pad1.33x1.80mm_HandSolder
CP107: 100uF; C_Radial_D8.0mm_H11.5mm_P3.50mm
H701, H702, H703, H704, H705, H706, H707, H708, H709, H710, H711, H712: UNC 6-32; MountingHole_3.7mm_UTS_6_Pad_Via
H713, H714, H715, H716, H717, H718: M2.5; MountingHole_2.7mm_M2.5_clear_10mm
J100: Power; Molex_KK-254_AE-6410-06A_1x06_P2.54mm_Vertical

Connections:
+12V: C108.1, CP107.1, J100.6; also elsewhere on the board
GND: C104.2, C108.2, CP107.2, H701.1, H702.1, H703.1, H704.1, H705.1, H706.1, H707.1, H708.1, H709.1, H710.1, H711.1, H712.1, J100.3, J100.4, J100.5; also elsewhere on the board

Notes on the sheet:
Collect power from PSU
Mounting holes for DOP modules
Main mounting holes

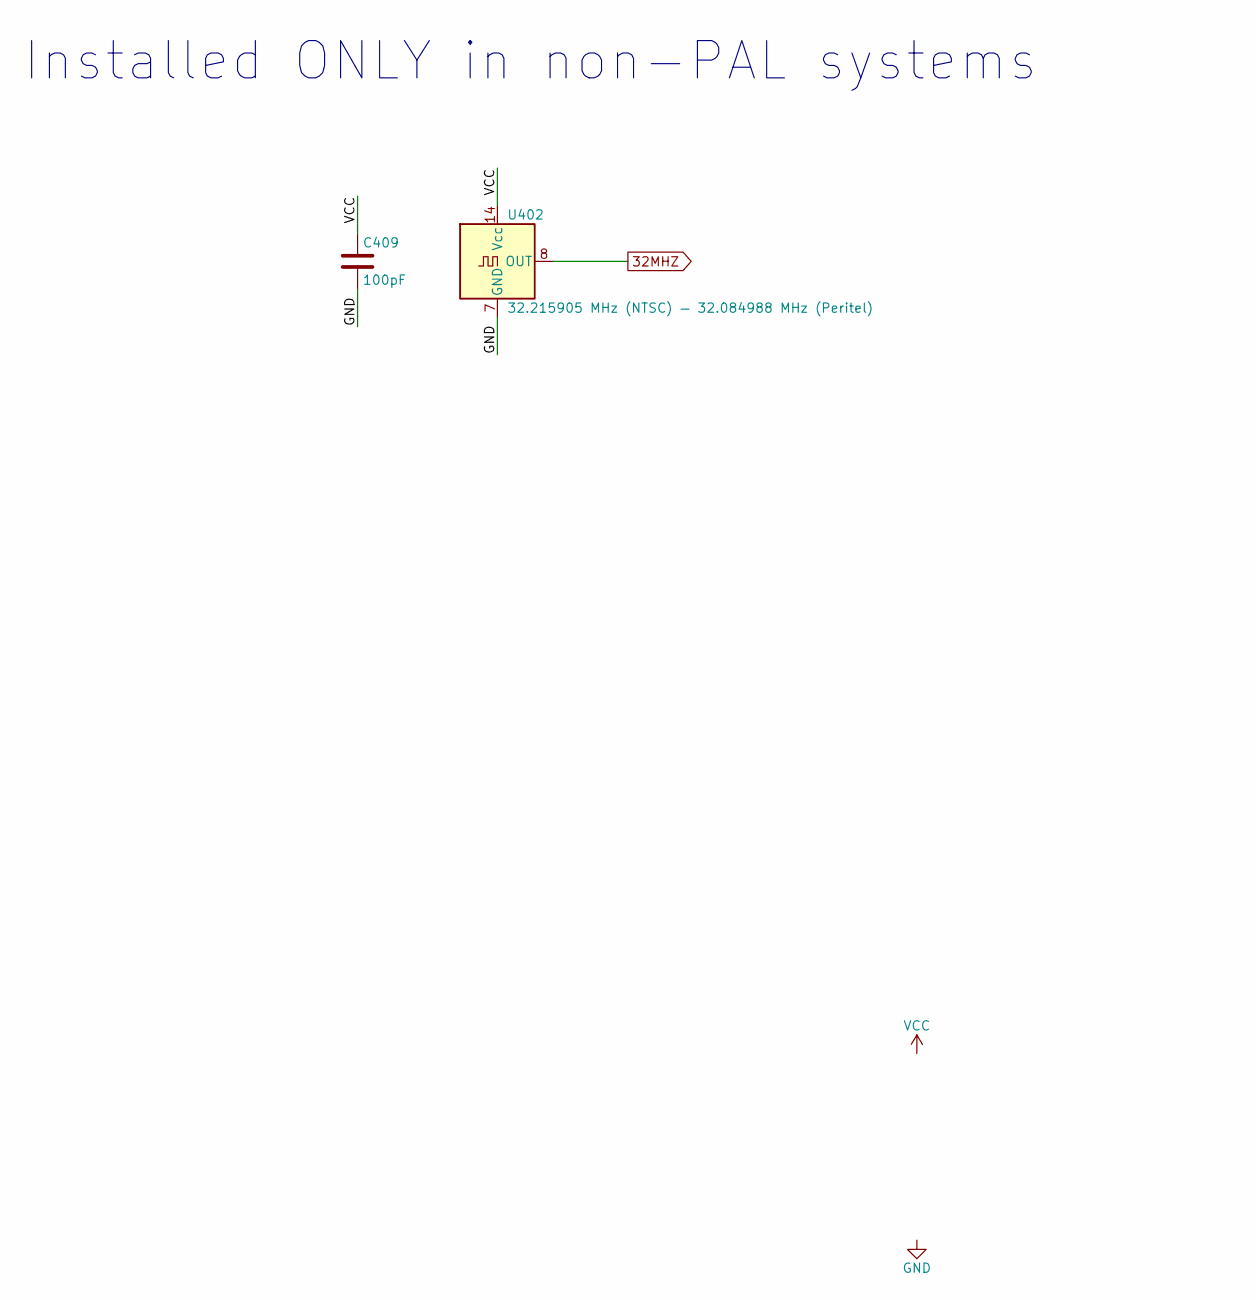
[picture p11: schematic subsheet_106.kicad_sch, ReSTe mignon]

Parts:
C409: 100pF; C_1206_3216Metric_Pad1.33x1.80mm_HandSolder
U402: 32.215905 MHz (NTSC) — 32.084988 MHz (Peritel); Oscillator_DIP-14

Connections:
32MHZ: U402.8 (OUT); also elsewhere on the board
GND: C409.2, U402.7 (GND); also elsewhere on the board

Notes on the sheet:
Installed ONLY in non-PAL systems

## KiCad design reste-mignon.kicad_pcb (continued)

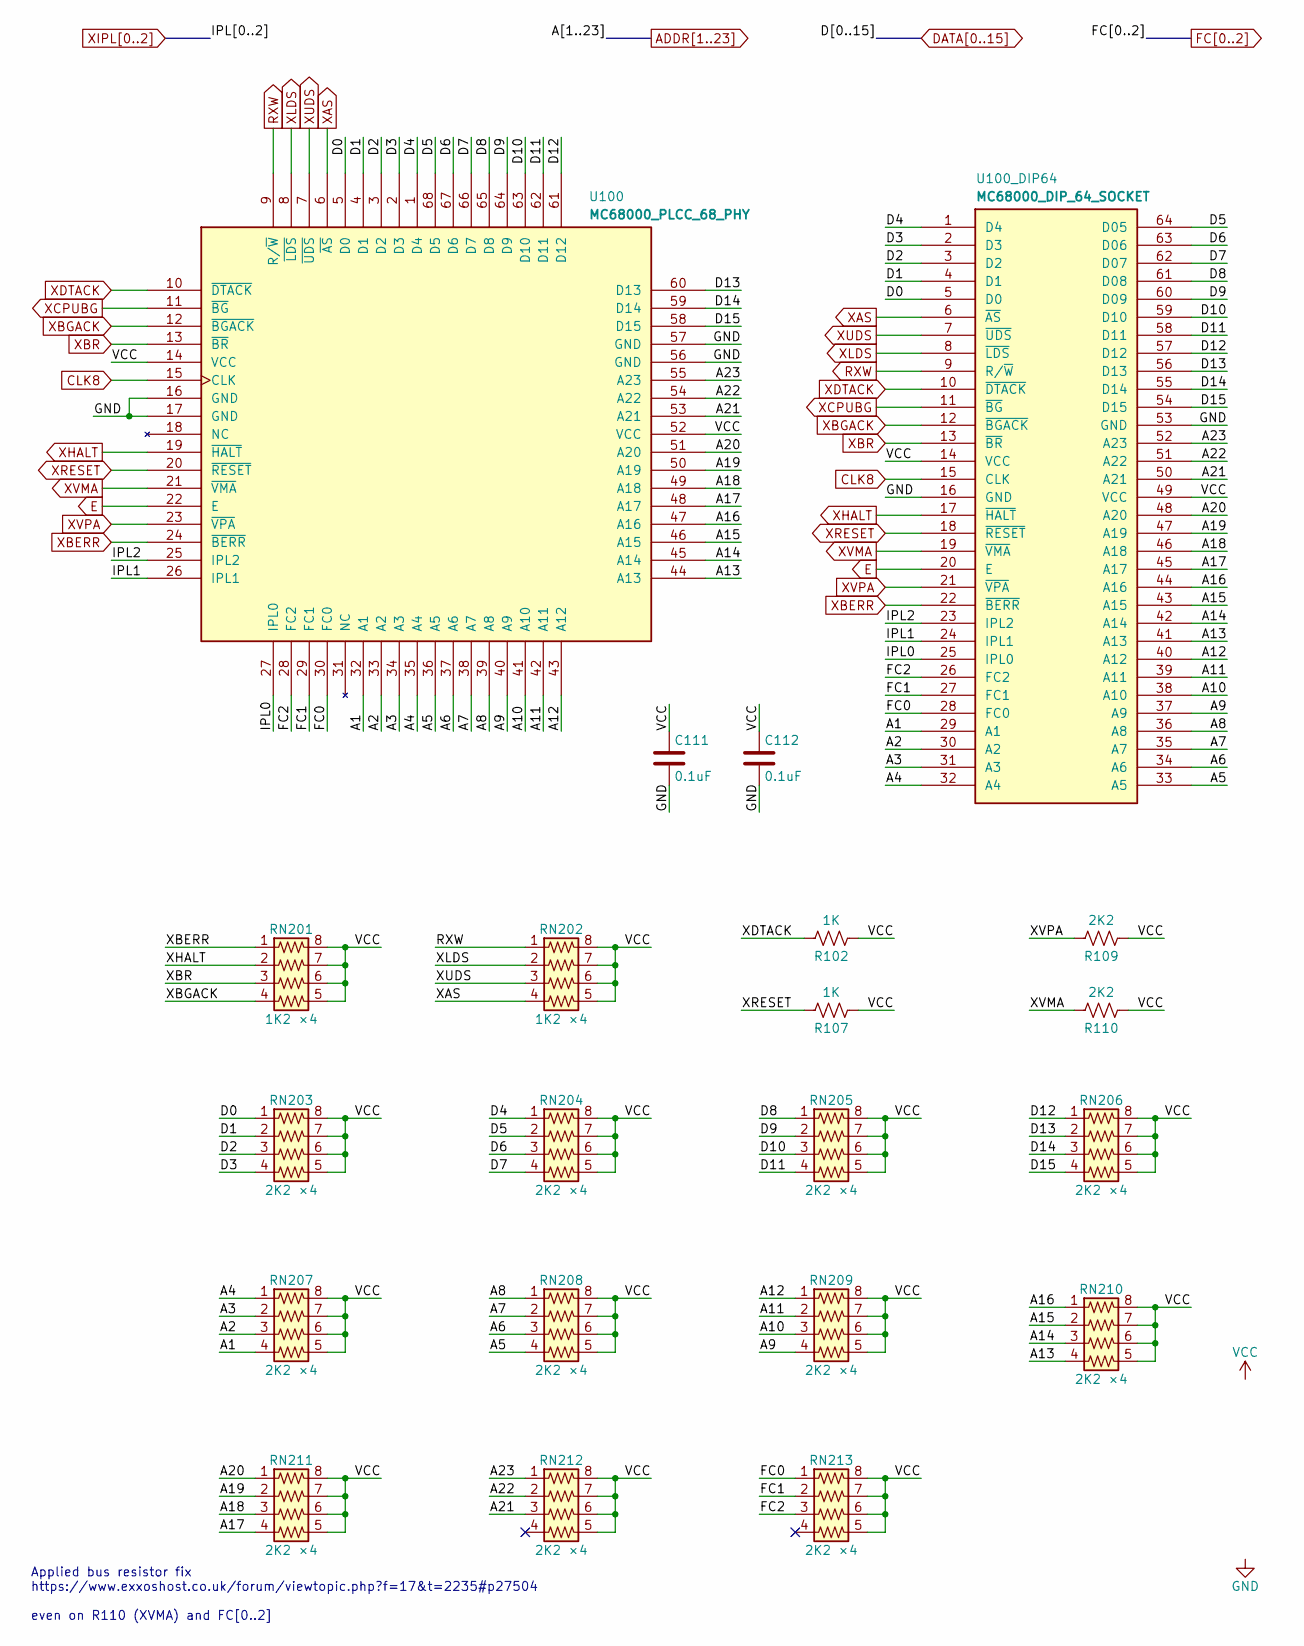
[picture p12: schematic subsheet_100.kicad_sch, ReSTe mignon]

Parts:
C111, C112: 0.1uF; C_1206_3216Metric_Pad1.33x1.80mm_HandSolder
R102, R107: 1K; R_1206_3216Metric_Pad1.30x1.75mm_HandSolder
R109, R110: 2K2; R_1206_3216Metric_Pad1.30x1.75mm_HandSolder
RN201, RN202: 1K2 ×4; R_Array_Convex_4x0603
RN203, RN204, RN205, RN206, RN207, RN208, RN209, RN210, RN211, RN212, RN213: 2K2 ×4; R_Array_Convex_4x0603
U100: MC68000_PLCC_68_PHY; PLCC-68_THT-Socket
U100_DIP64: MC68000_DIP_64_SOCKET; DIP-64_W22.86mm_Socket_LongPads

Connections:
ADDR22: RN212.2 (R2.1), U100.54 (A22), U100_DIP64.51 (A22); also elsewhere on the board
CLK8: U100.15 (CLK), U100_DIP64.15 (CLK); also elsewhere on the board
DATA0: RN203.1 (R1.1), U100.5 (D0), U100_DIP64.5 (D0); also elsewhere on the board
DATA1: RN203.2 (R2.1), U100.4 (D1), U100_DIP64.4 (D1); also elsewhere on the board
DATA2: RN203.3 (R3.1), U100.3 (D2), U100_DIP64.3 (D2); also elsewhere on the board
DATA3: RN203.4 (R4.1), U100.2 (D3), U100_DIP64.2 (D3); also elsewhere on the board
DATA4: RN204.1 (R1.1), U100.1 (D4), U100_DIP64.1 (D4); also elsewhere on the board
DATA5: RN204.2 (R2.1), U100.68 (D5), U100_DIP64.64 (D05); also elsewhere on the board
DATA6: RN204.3 (R3.1), U100.67 (D6), U100_DIP64.63 (D06); also elsewhere on the board
DATA7: RN204.4 (R4.1), U100.66 (D7), U100_DIP64.62 (D07); also elsewhere on the board
DATA8: RN205.1 (R1.1), U100.65 (D8), U100_DIP64.61 (D08); also elsewhere on the board
DATA9: RN205.2 (R2.1), U100.64 (D9), U100_DIP64.60 (D09); also elsewhere on the board
DATA10: RN205.3 (R3.1), U100.63 (D10), U100_DIP64.59 (D10); also elsewhere on the board
DATA11: RN205.4 (R4.1), U100.62 (D11), U100_DIP64.58 (D11); also elsewhere on the board
DATA12: RN206.1 (R1.1), U100.61 (D12), U100_DIP64.57 (D12); also elsewhere on the board
DATA13: RN206.2 (R2.1), U100.60 (D13), U100_DIP64.56 (D13); also elsewhere on the board
DATA14: RN206.3 (R3.1), U100.59 (D14), U100_DIP64.55 (D14); also elsewhere on the board
DATA15: RN206.4 (R4.1), U100.58 (D15), U100_DIP64.54 (D15); also elsewhere on the board
E: U100.22 (E), U100_DIP64.20 (E); also elsewhere on the board
FC0: RN213.1 (R1.1), U100.30 (FC0), U100_DIP64.28 (FC0); also elsewhere on the board
FC1: RN213.2 (R2.1), U100.29 (FC1), U100_DIP64.27 (FC1); also elsewhere on the board
FC2: RN213.3 (R3.1), U100.28 (FC2), U100_DIP64.26 (FC2); also elsewhere on the board
GND: C111.2, C112.2, U100.16 (GND), U100.17 (GND), U100.56 (GND), U100.57 (GND), U100_DIP64.16 (GND), U100_DIP64.53 (GND); also elsewhere on the board
RXW: RN202.1 (R1.1), U100.9 (R/~W), U100_DIP64.9 (R/~W); also elsewhere on the board
XAS: RN202.4 (R4.1), U100.6 (~AS), U100_DIP64.6 (~AS); also elsewhere on the board
XCPUBG: U100.11 (~BG), U100_DIP64.11 (~BG); also elsewhere on the board
XDTACK: R102.2, U100.10 (~DTACK), U100_DIP64.10 (~DTACK); also elsewhere on the board
XIPL0: U100.27 (IPL0), U100_DIP64.25 (IPL0); also elsewhere on the board
XIPL1: U100.26 (IPL1), U100_DIP64.24 (IPL1); also elsewhere on the board
XIPL2: U100.25 (IPL2), U100_DIP64.23 (IPL2); also elsewhere on the board
XLDS: RN202.2 (R2.1), U100.8 (~LDS), U100_DIP64.8 (~LDS); also elsewhere on the board
XRESET: R107.2, U100.20 (~RESET), U100_DIP64.18 (~RESET); also elsewhere on the board
XUDS: RN202.3 (R3.1), U100.7 (~UDS), U100_DIP64.7 (~UDS); also elsewhere on the board
XVMA: R110.2, U100.21 (~VMA), U100_DIP64.19 (~VMA); also elsewhere on the board
XVPA: R109.2, U100.23 (~VPA), U100_DIP64.21 (~VPA); also elsewhere on the board

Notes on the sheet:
Applied bus resistor fix https://www.exxoshost.co.uk/forum/viewtopic.php?f=17&t=2235#p27504 even on R110 (XVMA) and FC[0..2]

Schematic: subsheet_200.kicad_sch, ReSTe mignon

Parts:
C200, C201, C227: 0.1uF; C_1206_3216Metric_Pad1.33x1.80mm_HandSolder
D202: 1N914; D_SOD-123F
J200: DIN-5S — MIDI OUT/THRU; socket-din-5
J201: DIN-5S — MIDI IN; socket-din-5
R207: 220; R_1206_3216Metric_Pad1.30x1.75mm_HandSolder
R209: 1K; R_1206_3216Metric_Pad1.30x1.75mm_HandSolder
RN901: 4K7 ×4; R_Array_Convex_4x0603
RN902: 220 ×4; R_Array_Convex_4x0603
U200: MC6850_PHY; DIP-24_W15.24mm_LongPads
U208: PC900_PHY; DIP-6_W7.62mm_LongPads
U210: 7406_PHY; DIP-14_W7.62mm_LongPads

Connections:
/U200 — Acia 1 to MIDI IO/midi_out: RN902.4 (R4.1), U210.8 (4Y)
/U200 — Acia 1 to MIDI IO/not_rx: RN901.2 (R2.1), U210.11 (5A), U210.12 (6Y)
/U200 — Acia 1 to MIDI IO/not_tx: RN901.3 (R3.1), U210.6 (3Y), U210.9 (4A)
/U200 — Acia 1 to MIDI IO/rx: RN901.1 (R1.1), U200.2 (RXDAT), U208.4 (VO), U210.13 (6A)
/U200 — Acia 1 to MIDI IO/tx: U200.6 (TXDAT), U210.5 (3A)
ACIA_IRQ: R209.1, U200.7 (~IRQ); also elsewhere on the board
DATA8: U200.22 (D0); also elsewhere on the board
DATA9: U200.21 (D1); also elsewhere on the board
DATA10: U200.20 (D2); also elsewhere on the board
DATA11: U200.19 (D3); also elsewhere on the board
DATA12: U200.18 (D4); also elsewhere on the board
DATA13: U200.17 (D5); also elsewhere on the board
DATA14: U200.16 (D6); also elsewhere on the board
DATA15: U200.15 (D7); also elsewhere on the board
E: U200.14 (E); also elsewhere on the board
GND: C200.2, C201.2, C227.2, J200.2, J200.SH (Shield), J201.SH (Shield), U200.1 (GND), U200.9 (~CS2), U200.23 (~DCD), U200.24 (~CTS), U208.5 (GND), U210.7 (GND); also elsewhere on the board
KHZ500: U200.3 (TXCLK), U200.4 (RXCLK); also elsewhere on the board
N6850: U200.8 (CS0); also elsewhere on the board
unnamed: D202.1 (K), R207.2, U208.1 (Anode)
unnamed: D202.2 (A), J201.5, U208.2 (Cathode)
unnamed: J200.1, RN902.8 (R1.2)
unnamed: J200.5, RN902.5 (R4.2)
unnamed: J201.4, R207.1
RESET: U210.1 (1A), U210.3 (2A); also elsewhere on the board
RXW: U200.13 (R/~W); also elsewhere on the board
XRESET: U210.2 (1Y); also elsewhere on the board

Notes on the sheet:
WARNING ! The pinout is mirrored.

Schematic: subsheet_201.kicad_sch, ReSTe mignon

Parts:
C210, C1001: 0.1uF; C_1206_3216Metric_Pad1.33x1.80mm_HandSolder
C1002, C1003: 1nF; C_1206_3216Metric_Pad1.33x1.80mm_HandSolder
J202: BRS — To IKBD; PinHeader_1x08_P2.54mm_Vertical_Ikbd
J1001: RJ11S - To Mega ST(e)/TT Keyboard; RJ12_Amphenol_54601
R210: 10K; R_1206_3216Metric_Pad1.30x1.75mm_HandSolder
U201: MC6850_PHY; DIP-24_W15.24mm_LongPads

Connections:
/U201 — Acia 2 to IKBD IO/rx: C1003.1, J202.5, J1001.4, R210.1, U201.2 (RXDAT)
/U201 — Acia 2 to IKBD IO/tx: C1002.1, J202.6, J1001.3, U201.6 (TXDAT)
ACIA_IRQ: U201.7 (~IRQ); also elsewhere on the board
BD0SEL: J202.3; also elsewhere on the board
DATA8: U201.22 (D0); also elsewhere on the board
DATA9: U201.21 (D1); also elsewhere on the board
DATA10: U201.20 (D2); also elsewhere on the board
DATA11: U201.19 (D3); also elsewhere on the board
DATA12: U201.18 (D4); also elsewhere on the board
DATA13: U201.17 (D5); also elsewhere on the board
DATA14: U201.16 (D6); also elsewhere on the board
DATA15: U201.15 (D7); also elsewhere on the board
E: U201.14 (E); also elsewhere on the board
GND: C210.2, C1001.2, C1002.2, C1003.2, J202.1, J202.8, J1001.5, J1001.6, U201.1 (GND), U201.23 (~DCD), U201.24 (~CTS); also elsewhere on the board
KHZ500: U201.3 (TXCLK), U201.4 (RXCLK); also elsewhere on the board
N6850: U201.8 (CS0); also elsewhere on the board
RXW: U201.13 (R/~W); also elsewhere on the board
XRESET: J202.7; also elsewhere on the board

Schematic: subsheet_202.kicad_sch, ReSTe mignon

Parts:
C214: 0.1uF; C_1206_3216Metric_Pad1.33x1.80mm_HandSolder
J203: DB-25S Parallel port; DSUB-25_Female_Horizontal_P2.77x2.84mm_EdgePinOffset7.70mm_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
J1101: Parallel and Serial breakout; PinHeader_2x14_P2.54mm_Vertical
R212: 3K3; R_1206_3216Metric_Pad1.30x1.75mm_HandSolder
R220: 1K; R_1206_3216Metric_Pad1.30x1.75mm_HandSolder
U202: YM2149_PHY; DIP-40_W15.24mm_LongPads

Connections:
/U202 — PSG and Parallel IO/pd0: J203.2, J1101.5, U202.13 (IOB0)
/U202 — PSG and Parallel IO/pd1: J203.3, J1101.7, U202.12 (IOB1)
/U202 — PSG and Parallel IO/pd2: J203.4, J1101.9, U202.11 (IOB2)
/U202 — PSG and Parallel IO/pd3: J203.5, J1101.11, U202.10 (IOB3)
/U202 — PSG and Parallel IO/pd4: J203.6, J1101.13, U202.9 (IOB4)
/U202 — PSG and Parallel IO/pd5: J203.7, J1101.15, U202.8 (IOB5)
/U202 — PSG and Parallel IO/pd6: J203.8, J1101.17, U202.7 (IOB6)
/U202 — PSG and Parallel IO/pd7: J203.9, J1101.19, U202.6 (IOB7)
/U202 — PSG and Parallel IO/strobe: J203.1, J1101.3, U202.16 (IOA5)
AUDIOS: R220.2, U202.3 (ACA), U202.4 (ACB), U202.38 (ACC); also elsewhere on the board
CLK2: U202.22 (CLOCK); also elsewhere on the board
D0SEL: U202.20 (IOA1); also elsewhere on the board
D1SEL: U202.19 (IOA2); also elsewhere on the board
DATA8: U202.37 (DA0); also elsewhere on the board
DATA9: U202.36 (DA1); also elsewhere on the board
DATA10: U202.35 (DA2); also elsewhere on the board
DATA11: U202.34 (DA3); also elsewhere on the board
DATA12: U202.33 (DA4); also elsewhere on the board
DATA13: U202.32 (DA5); also elsewhere on the board
DATA14: U202.31 (DA6); also elsewhere on the board
DATA15: U202.30 (DA7); also elsewhere on the board
GND: C214.2, J203.18, J203.19, J203.20, J203.21, J203.22, J203.23, J203.24, J203.25, J203.SH (Shield), J1101.2, J1101.4, J1101.6, J1101.8, J1101.10, J1101.12, J1101.14, J1101.16, J1101.18, J1101.20, J1101.22, J1101.24, J1101.26, J1101.28, R220.1, U202.1 (GND), U202.24 (~A9); also elsewhere on the board
PARALLEL_BUSY: J203.11, J1101.1, R212.2; also elsewhere on the board
S0SEL: U202.21 (IOA0); also elsewhere on the board
SERIAL_DIR: U202.17 (IOA4); also elsewhere on the board
SERIAL_RTS: U202.18 (IOA3); also elsewhere on the board
SNDCS: U202.29 (BC1); also elsewhere on the board
SNDIR: U202.27 (BDIR); also elsewhere on the board
XRESET: U202.23 (~RESET); also elsewhere on the board

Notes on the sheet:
To LMC1992
To MFP

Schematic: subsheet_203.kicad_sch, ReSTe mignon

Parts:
C219, C220: 30pF; C_1206_3216Metric_Pad1.33x1.80mm_HandSolder
C221, C229, C230, C900: 0.1uF; C_1206_3216Metric_Pad1.33x1.80mm_HandSolder
R215, R216, R217: 4K7; R_1206_3216Metric_Pad1.30x1.75mm_HandSolder
U203: MC68901_DIP_48_PHY; DIP-48_W15.24mm_Socket_LongPads
U209: 74LS86_PHY; DIP-14_W7.62mm_LongPads
U211: 74LS04_PHY; DIP-14_W7.62mm_LongPads
U900: 74LS164_PHY; DIP-14_W7.62mm_LongPads
Y200: 2.4576 MHz; Crystal_HC18-U_Horizontal

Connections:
/U203 — MFP 68901/hsync_xor_vsync: U209.3 (1Y), U211.5 (3A)
/U203 — MFP 68901/not_xsint: U209.13 (4B), U211.2 (1Y), U900.1 (A), U900.2 (B), U900.9 (~CLR)
/U203 — MFP 68901/not_xsint_XOR_monomon: U203.29 (I7), U209.11 (4Y)
/U203 — MFP 68901/tai: U203.19 (TAI), U900.13 (QH)
/U203 — MFP 68901/timer_d: U203.7 (TC), U203.10 (RC), U203.16 (TDO)
/U203 — MFP 68901/xtal1: C220.1, U203.17 (XTAL1), Y200.2
/U203 — MFP 68901/xtal2: C219.1, U203.18 (XTAL2), Y200.1
ACIA_IRQ: U203.26 (I4); also elsewhere on the board
CLK2: U900.8 (CLK); also elsewhere on the board
CLK4: U203.35 (CLK); also elsewhere on the board
DATA0: U203.37 (D0); also elsewhere on the board
DATA1: U203.38 (D1); also elsewhere on the board
DATA2: U203.39 (D2); also elsewhere on the board
DATA3: U203.40 (D3); also elsewhere on the board
DATA4: U203.41 (D4); also elsewhere on the board
DATA5: U203.42 (D5); also elsewhere on the board
DATA6: U203.43 (D6); also elsewhere on the board
DATA7: U203.44 (D7); also elsewhere on the board
DE: U203.20 (TBI); also elsewhere on the board
GND: C219.2, C220.2, C221.2, C229.2, C230.2, C900.2, U203.34 (~IEI), U203.36 (GND), U209.4 (2A), U209.5 (2B), U209.7 (GND), U209.9 (3A), U209.10 (3B), U211.7 (GND), U211.9 (4A), U211.11 (5A), U211.13 (6A), U900.7 (GND); also elsewhere on the board
HSYNC: U209.1 (1A); also elsewhere on the board
MONOMON: R215.1, U209.12 (4A); also elsewhere on the board
PARALLEL_BUSY: U203.22 (I0); also elsewhere on the board
RXW: U203.1 (R/~W); also elsewhere on the board
SD7: U211.4 (2Y); also elsewhere on the board
SERIAL_CD: U203.23 (I1); also elsewhere on the board
SERIAL_CTS: U203.24 (I2); also elsewhere on the board
SERIAL_RI: U203.28 (I6); also elsewhere on the board
SERIAL_RX: U203.9 (SI); also elsewhere on the board
SERIAL_TX: U203.8 (SO); also elsewhere on the board
SHIFTER_SD7: U211.3 (2A); also elsewhere on the board
VSYNC: U209.2 (1B); also elsewhere on the board
XBLTINT: R216.1, U203.25 (I3); also elsewhere on the board
XDISKINT: U203.27 (I5); also elsewhere on the board
XDTACK: U203.46 (~DTACK); also elsewhere on the board
XIACK: U203.45 (~IACK); also elsewhere on the board
XLDS: U203.47 (~DS); also elsewhere on the board
XMFPCS: U203.48 (~CS); also elsewhere on the board
XMFPINT: R217.1, U203.32 (~IRQ); also elsewhere on the board
XRESET: U203.21 (~RESET); also elsewhere on the board
XSINT: U211.1 (1A); also elsewhere on the board

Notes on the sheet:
TODO : verify that HSYNC xor VSYNC is no more used

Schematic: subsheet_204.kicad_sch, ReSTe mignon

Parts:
C203, C206, C228: 0.1uF; C_1206_3216Metric_Pad1.33x1.80mm_HandSolder
C222, C223, C224, C225: 100pF; C_1206_3216Metric_Pad1.33x1.80mm_HandSolder
J204: DB-25P Serial Port RS-232; DSUB-25_Male_Horizontal_P2.77x2.84mm_EdgePinOffset7.70mm_Ho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
U206: MC1488_QUAD_LINE_EIA-232D_DRIVER_PHY; DIP-14_W7.62mm_LongPads
U207: MC1489_QUAD_LINE_EIA-232D_RECEIVERS_PHY; DIP-14_W7.62mm_LongPads

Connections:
-12V: C203.1, U206.1 (VEE); also elsewhere on the board
/J204 — RS-232 IO/rca: C222.1, U207.2 (RCA)
/J204 — RS-232 IO/rcb: C223.1, U207.5 (RCB)
/J204 — RS-232 IO/rcc: C225.1, U207.9 (RCC)
/J204 — RS-232 IO/rcd: C224.1, U207.12 (RCD)
/J204 — RS-232 IO/rs_232_cd: J204.8, U207.13 (ID)
/J204 — RS-232 IO/rs_232_cts: J204.5, U207.4 (IB)
/J204 — RS-232 IO/rs_232_dir: J204.20, U206.3 (OA)
/J204 — RS-232 IO/rs_232_ri: J204.22, U207.10 (IC)
/J204 — RS-232 IO/rs_232_rts: J204.4, U206.8 (OC)
/J204 — RS-232 IO/rs_232_rx: J204.3, U207.1 (IA)
/J204 — RS-232 IO/rs_232_tx: J204.2, U206.6 (OB)
G12V: C206.1, U206.14 (Vcc); also elsewhere on the board
GND: C203.2, C206.2, C222.2, C223.2, C224.2, C225.2, C228.2, J204.1, J204.7, J204.SH (Shield), U206.7 (GND), U206.12 (ID2), U206.13 (ID1), U207.7 (GND); also elsewhere on the board
SERIAL_CD: U207.11 (OD); also elsewhere on the board
SERIAL_CTS: U207.6 (OB); also elsewhere on the board
SERIAL_DIR: U206.2 (IA); also elsewhere on the board
SERIAL_RI: U207.8 (OC); also elsewhere on the board
SERIAL_RTS: U206.9 (IC2), U206.10 (IC1); also elsewhere on the board
SERIAL_RX: U207.3 (OA); also elsewhere on the board
SERIAL_TX: U206.4 (IB1), U206.5 (IB2); also elsewhere on the board

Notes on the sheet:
TODO : replace by a DB-9P Serial Port

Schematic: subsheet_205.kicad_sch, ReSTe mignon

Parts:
C207, C217: 0.1uF; C_1206_3216Metric_Pad1.33x1.80mm_HandSolder
C208: 150pF; C_1206_3216Metric_Pad1.33x1.80mm_HandSolder
C209: 330pF; C_1206_3216Metric_Pad1.33x1.80mm_HandSolder
C218: 270pF; C_1206_3216Metric_Pad1.33x1.80mm_HandSolder
CP202, CP204, CP205, CP215: 4.7uF; C_Radial_D5.0mm_H11.0mm_P2.00mm
CP216: 470uF; C_Radial_D12.5mm_H20.0mm_P5.00mm
D200, D201, D203: 1N914; D_SOD-123F
L203, L208: 220uH; L_Radial_D15.0mm_P5.00mm
R203: 5.1; R_1206_3216Metric_Pad1.30x1.75mm_HandSolder
R206: 12K; R_1206_3216Metric_Pad1.30x1.75mm_HandSolder
R208, R213: 1K2; R_1206_3216Metric_Pad1.30x1.75mm_HandSolder
R211: 1; R_1206_3216Metric_Pad1.30x1.75mm_HandSolder
R214: 3K9; R_1206_3216Metric_Pad1.30x1.75mm_HandSolder
U204, U205: TL497A_DIP-14_500MA_PEAK_STEP-UP_STEP-DOWN_INVERT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; DIP-14_W7.62mm_LongPads

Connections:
-5V: CP215.2, CP216.2, D203.2 (A), R213.1, U205.4 (SUBSTRATE); also elsewhere on the board
-12V: CP204.2, D200.2 (A); also elsewhere on the board
/U204 U205 — G12V -12V -5V/col_1: CP202.1, L203.2, U204.7 (ANODE), U204.10 (COL_OUT)
/U204 U205 — G12V -12V -5V/freq_1: C209.1, U204.3 (FREQ_CONTROL)
/U204 U205 — G12V -12V -5V/freq_2: C218.1, U205.3 (FREQ_CONTROL)
/U204 U205 — G12V -12V -5V/in_1: R206.2, R208.1, U204.1 (COMP_INPUT)
/U204 U205 — G12V -12V -5V/in_2: R213.2, R214.1, U205.1 (COMP_INPUT)
/U204 U205 — G12V -12V -5V/lim_1: C208.1, L203.1, R203.1, U204.13 (CUR_LIM_SENSE)
G12V: CP205.1, R206.1, U204.6 (CATHODE); also elsewhere on the board
GND: C207.2, C208.2, C209.2, C217.2, C218.2, CP204.1, CP205.2, CP215.1, CP216.1, D201.1 (K), L208.2, R208.2, R214.2, U204.2 (INHIBIT), U204.4 (SUBSTRATE), U204.5 (GND), U204.8 (EMIT_OUT), U205.2 (INHIBIT), U205.5 (GND); also elsewhere on the board
unnamed: CP202.2, D200.1 (K), D201.2 (A)
unnamed: D203.1 (K), L208.1, U205.8 (EMIT_OUT)
unnamed: R211.2, U205.10 (COL_OUT), U205.13 (CUR_LIM_SENSE)

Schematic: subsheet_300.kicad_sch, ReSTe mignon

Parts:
C226, C302: 0.1uF; C_1206_3216Metric_Pad1.33x1.80mm_HandSolder
R303: 1K; R_1206_3216Metric_Pad1.30x1.75mm_HandSolder
RN1501, RN1502: 10K ×4; R_Array_Convex_4x0603
U300_DIP40: ST_DMA_DIP40_PHY; DIP-40_W15.24mm_Socket_LongPads
U300_PLCC44: ST_DMA_PLCC44_PHY; PLCC-44_THT-Socket

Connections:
CADDR1: U300_DIP40.26 (CA1), U300_PLCC44.28 (CA1); also elsewhere on the board
CADDR2: U300_DIP40.27 (CA2), U300_PLCC44.29 (CA2); also elsewhere on the board
CDATA0: RN1501.1 (R1.1), U300_DIP40.36 (CD0), U300_PLCC44.39 (CD0); also elsewhere on the board
CDATA1: RN1501.2 (R2.1), U300_DIP40.35 (CD1), U300_PLCC44.38 (CD1); also elsewhere on the board
CDATA2: RN1501.3 (R3.1), U300_DIP40.34 (CD2), U300_PLCC44.37 (CD2); also elsewhere on the board
CDATA3: RN1501.4 (R4.1), U300_DIP40.33 (CD3), U300_PLCC44.36 (CD3); also elsewhere on the board
CDATA4: RN1502.1 (R1.1), U300_DIP40.32 (CD4), U300_PLCC44.35 (CD4); also elsewhere on the board
CDATA5: RN1502.2 (R2.1), U300_DIP40.31 (CD5), U300_PLCC44.34 (CD5); also elsewhere on the board
CDATA6: RN1502.3 (R3.1), U300_DIP40.30 (CD6), U300_PLCC44.33 (CD6); also elsewhere on the board
CDATA7: RN1502.4 (R4.1), U300_DIP40.29 (CD7), U300_PLCC44.31 (CD7); also elsewhere on the board
CLK8: U300_DIP40.39 (CLK), U300_PLCC44.43 (CLK); also elsewhere on the board
DATA0: U300_DIP40.4 (D0), U300_PLCC44.5 (D0); also elsewhere on the board
DATA1: U300_DIP40.5 (D1), U300_PLCC44.6 (D1); also elsewhere on the board
DATA2: U300_DIP40.6 (D2), U300_PLCC44.7 (D2); also elsewhere on the board
DATA3: U300_DIP40.7 (D3), U300_PLCC44.8 (D3); also elsewhere on the board
DATA4: U300_DIP40.8 (D4), U300_PLCC44.9 (D4); also elsewhere on the board
DATA5: U300_DIP40.9 (D5), U300_PLCC44.10 (D5); also elsewhere on the board
DATA6: U300_DIP40.10 (D6), U300_PLCC44.11 (D6); also elsewhere on the board
DATA7: U300_DIP40.11 (D7), U300_PLCC44.12 (D7); also elsewhere on the board
DATA8: U300_DIP40.12 (D8), U300_PLCC44.13 (D8); also elsewhere on the board
DATA9: U300_DIP40.13 (D9), U300_PLCC44.14 (D9); also elsewhere on the board
DATA10: U300_DIP40.14 (D10), U300_PLCC44.15 (D10); also elsewhere on the board
DATA11: U300_DIP40.15 (D11), U300_PLCC44.16 (D11); also elsewhere on the board
DATA12: U300_DIP40.16 (D12), U300_PLCC44.17 (D12); also elsewhere on the board
DATA13: U300_DIP40.17 (D13), U300_PLCC44.18 (D13); also elsewhere on the board
DATA14: U300_DIP40.18 (D14), U300_PLCC44.19 (D14); also elsewhere on the board
DATA15: U300_DIP40.19 (D15), U300_PLCC44.20 (D15); also elsewhere on the board
DMA_ACK: U300_DIP40.37 (~ACK), U300_PLCC44.40 (~ACK); also elsewhere on the board
DMA_FDCS: U300_DIP40.22 (~FDCS), U300_PLCC44.24 (~FDCS); also elsewhere on the board
DMA_FDRQ: U300_DIP40.21 (FDRQ), U300_PLCC44.23 (FDRQ); also elsewhere on the board
DMA_HDCS: U300_DIP40.24 (~HDCS), U300_PLCC44.26 (~HDCS); also elsewhere on the board
DMA_HDRQ: U300_DIP40.23 (HDRQ), U300_PLCC44.25 (HDRQ); also elsewhere on the board
DMA_RW: U300_DIP40.25 (CR/~W), U300_PLCC44.27 (CR/~W); also elsewhere on the board
GND: C226.2, C302.2, U300_DIP40.20 (GND), U300_DIP40.28 (GND), U300_PLCC44.4 (GND), U300_PLCC44.22 (GND), U300_PLCC44.30 (TESTIN), U300_PLCC44.32 (GND), U300_PLCC44.42 (GND); also elsewhere on the board
RDY: R303.1, U300_DIP40.38 (RDY), U300_PLCC44.41 (RDY); also elsewhere on the board
RXW: U300_DIP40.1 (R/~W), U300_PLCC44.1 (R/~W); also elsewhere on the board
XFCS: U300_DIP40.3 (~FCS), U300_PLCC44.3 (~FCS); also elsewhere on the board

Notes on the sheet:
I found out that C226 is not present in sheet 2. Thus I believe that it is in fact the second bypass capacitor for U300.
For motherboards with PLCC-44 version (my motherboard), pinout taken from the schematics of the Mega STE and the STBook
For motherboards with DIP-40 version (original schematics)
DMA data bus pull-up fix https://www.exxoshost.co.uk/forum/viewtopic.php?f=17&t=1417

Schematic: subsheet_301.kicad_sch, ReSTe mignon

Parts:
C303, C306, C307, C1601: 0.1uF; C_1206_3216Metric_Pad1.33x1.80mm_HandSolder
J301: DB-19S ACSI Port; DSUB-19_Female_Horizontal_P2.77x2.84mm_EdgePinOffset7.70mm_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
J1601: Like MegaSTE J402; PinHeader_2x15_P2.54mm_Vertical
RN1601, RN1602, RN1603: 68 ×4; R_Array_Convex_4x0603
U302: 74LS245_PHY; DIP-20_W7.62mm_LongPads
U306: 74LS74_PHY; DIP-14_W7.62mm_LongPads
U307: 74LS244_PHY; DIP-20_W7.62mm_LongPads

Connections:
/J301 — ACSI Port/HD0: J1601.2, U302.2 (A1)
/J301 — ACSI Port/HD1: J1601.4, U302.3 (A2)
/J301 — ACSI Port/HD2: J1601.6, U302.4 (A3)
/J301 — ACSI Port/HD3: J1601.8, U302.5 (A4)
/J301 — ACSI Port/HD4: J1601.10, U302.6 (A5)
/J301 — ACSI Port/HD5: J1601.12, U302.7 (A6)
/J301 — ACSI Port/HD6: J1601.14, U302.8 (A7)
/J301 — ACSI Port/HD7: J1601.16, U302.9 (A8)
/J301 — ACSI Port/acsi_12: J301.12, J1601.17, U307.9 (2Y1)
/J301 — ACSI Port/hd_enable: U302.19 (~OE), U306.6 (~1Q)
/J301 — ACSI Port/hda0: J1601.20, RN1603.3 (R3.1), U307.7 (2Y2)
/J301 — ACSI Port/hdack: J1601.18, RN1603.2 (R2.1), U307.3 (2Y4)
/J301 — ACSI Port/hdcs: J1601.19, RN1603.1 (R1.1), U307.5 (2Y3)
/J301 — ACSI Port/hdrw: J1601.21, RN1603.4 (R4.1), U307.12 (1Y4)
ACSI_19_HDRQ: J301.19, J1601.22; also elsewhere on the board
BD0SEL: U307.18 (1Y1); also elsewhere on the board
CADDR1: U307.13 (2A2); also elsewhere on the board
CDATA0: U302.18 (B1); also elsewhere on the board
CDATA1: U302.17 (B2); also elsewhere on the board
CDATA2: U302.16 (B3); also elsewhere on the board
CDATA3: U302.15 (B4); also elsewhere on the board
CDATA4: U302.14 (B5); also elsewhere on the board
CDATA5: U302.13 (B6); also elsewhere on the board
CDATA6: U302.12 (B7); also elsewhere on the board
CDATA7: U302.11 (B8); also elsewhere on the board
CLK8: U306.3 (1CLK); also elsewhere on the board
D0SEL: U307.2 (1A1); also elsewhere on the board
DMA_ACK: U307.17 (2A4); also elsewhere on the board
DMA_FDCS: U306.1 (~1CLR), U306.2 (1D); also elsewhere on the board
DMA_HDCS: U307.15 (2A3); also elsewhere on the board
DMA_RW: U302.1 (DIR), U307.8 (1A4); also elsewhere on the board
GND: C303.2, C306.2, C307.2, C1601.2, J301.11, J301.13, J301.15, J301.17, J301.SH (Shield), J1601.25, J1601.27, J1601.29, U302.10 (GND), U306.7 (GND), U306.10 (~2PRE), U306.11 (2CLK), U306.12 (2D), U307.1 (~1G), U307.10 (GND), U307.19 (~2G); also elsewhere on the board
unnamed: J301.1, RN1601.8 (R1.2)
unnamed: J301.2, RN1601.7 (R2.2)
unnamed: J301.3, RN1601.6 (R3.2)
unnamed: J301.4, RN1601.5 (R4.2)
unnamed: J301.5, RN1602.8 (R1.2)
unnamed: J301.6, RN1602.7 (R2.2)
unnamed: J301.7, RN1602.6 (R3.2)
unnamed: J301.8, RN1602.5 (R4.2)
unnamed: J301.9, RN1603.8 (R1.2)
unnamed: J301.14, RN1603.7 (R2.2)
unnamed: J301.16, RN1603.6 (R3.2)
unnamed: J301.18, RN1603.5 (R4.2)
unnamed: J1601.1, RN1601.1 (R1.1)
unnamed: J1601.3, RN1601.2 (R2.1)
unnamed: J1601.5, RN1601.3 (R3.1)
unnamed: J1601.7, RN1601.4 (R4.1)
unnamed: J1601.9, RN1602.1 (R1.1)
unnamed: J1601.11, RN1602.2 (R2.1)
unnamed: J1601.13, RN1602.3 (R3.1)
unnamed: J1601.15, RN1602.4 (R4.1)
XHDINT: J301.10, J1601.23; also elsewhere on the board
XRESET: U307.11 (2A1); also elsewhere on the board

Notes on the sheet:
This connector is the same as in the MegaSTE (J402). One could plug the harddisk controller C103561-001
TODO : verify how to wire unused flip flop

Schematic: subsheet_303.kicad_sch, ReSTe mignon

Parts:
C300, C301: 0.1uF; C_1206_3216Metric_Pad1.33x1.80mm_HandSolder
U303: 8.010613 MHz; Oscillator_DIP-14
U304: 74LS74_PHY; DIP-14_W7.62mm_LongPads

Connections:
/U303 — SCLK & CLK2 clocks/half_sclk: U304.5 (1Q), U304.11 (2CLK)
CLK2: U304.9 (2Q); also elsewhere on the board
GND: C300.2, C301.2, U303.7 (GND), U304.7 (GND); also elsewhere on the board
unnamed: U304.2 (1D), U304.6 (~1Q)
unnamed: U304.8 (~2Q), U304.12 (2D)
SCLK: U303.8 (OUT), U304.3 (1CLK); also elsewhere on the board

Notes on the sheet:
To YM2149 and MFP 68901
To WD1772 and Shifter

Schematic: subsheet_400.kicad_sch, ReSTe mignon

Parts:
C402, C403, C404, C405, C406: 0.1uF; C_1206_3216Metric_Pad1.33x1.80mm_HandSolder
J1901: ROM[0..6] Breakout; PinSocket_2x07_P2.54mm_Vertical
R421: 1K; R_1206_3216Metric_Pad1.30x1.75mm_HandSolder
RN1901, RN1902: 33 ×4; R_Array_Convex_4x0603
RN1903, RN1904, RN1905: 68 ×4; R_Array_Convex_4x0603
U400: STE_GSTMCU_PHY; PQFP-144_28x28mm_P0.65mm

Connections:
/U400 — GSTMCU/cas0h: RN1901.2 (R2.1), U400.126 (~CAS0H)
/U400 — GSTMCU/cas0l: RN1901.3 (R3.1), U400.125 (~CAS0L)
/U400 — GSTMCU/cas1h: RN1902.2 (R2.1), U400.123 (~CAS1H)
/U400 — GSTMCU/cas1l: RN1902.3 (R3.1), U400.122 (~CAS1L)
/U400 — GSTMCU/ma0: RN1905.2 (R2.1), U400.110 (MAD0)
/U400 — GSTMCU/ma1: RN1905.1 (R1.1), U400.111 (MAD1)
/U400 — GSTMCU/ma2: RN1904.4 (R4.1), U400.112 (MAD2)
/U400 — GSTMCU/ma3: RN1904.3 (R3.1), U400.113 (MAD3)
/U400 — GSTMCU/ma4: RN1904.2 (R2.1), U400.114 (MAD4)
/U400 — GSTMCU/ma5: RN1904.1 (R1.1), U400.115 (MAD5)
/U400 — GSTMCU/ma6: RN1903.4 (R4.1), U400.116 (MAD6)
/U400 — GSTMCU/ma7: RN1903.3 (R3.1), U400.117 (MAD7)
/U400 — GSTMCU/ma8: RN1903.2 (R2.1), U400.118 (MAD8)
/U400 — GSTMCU/ma9: RN1903.1 (R1.1), U400.119 (MAD9)
/U400 — GSTMCU/ras0: RN1901.1 (R1.1), U400.127 (~RAS0)
/U400 — GSTMCU/ras1: RN1902.1 (R1.1), U400.124 (~RAS1)
/U400 — GSTMCU/we: RN1902.4 (R4.1), U400.121 (~WE)
ADDR22: U400.42 (A22); also elsewhere on the board
CLK4: U400.4 (CLK4); also elsewhere on the board
CLK8: U400.3 (CLK8); also elsewhere on the board
DATA0: U400.91 (D0); also elsewhere on the board
DATA1: U400.90 (D1); also elsewhere on the board
DATA2: U400.89 (D2); also elsewhere on the board
DATA3: U400.88 (D3); also elsewhere on the board
DATA4: U400.87 (D4); also elsewhere on the board
DATA5: U400.86 (D5); also elsewhere on the board
DATA6: U400.85 (D6); also elsewhere on the board
DATA7: U400.84 (D7); also elsewhere on the board
DATA8: U400.82 (D8); also elsewhere on the board
DATA9: U400.81 (D9); also elsewhere on the board
DATA10: U400.80 (D10); also elsewhere on the board
DATA11: U400.79 (D11); also elsewhere on the board
DATA12: U400.78 (D12); also elsewhere on the board
DATA13: U400.77 (D13); also elsewhere on the board
DATA14: U400.76 (D14); also elsewhere on the board
DATA15: U400.75 (D15); also elsewhere on the board
DE: U400.141 (DE); also elsewhere on the board
FC0: U400.40 (FC0); also elsewhere on the board
FC1: U400.39 (FC1); also elsewhere on the board
FC2: U400.38 (FC2); also elsewhere on the board
FDINT: U400.16 (FDINT); also elsewhere on the board
GND: C402.2, C403.2, C404.2, C405.2, C406.2, J1901.2, J1901.4, J1901.6, J1901.8, J1901.10, J1901.12, J1901.14, U400.1 (GND), U400.37 (GND), U400.73 (GND), U400.74 (TEST), U400.109 (GND), U400.128 (GND); also elsewhere on the board
HSYNC: U400.143 (~HSYNC); also elsewhere on the board
JOYWL: U400.102 (JOYWL); also elsewhere on the board
KHZ500: U400.6 (CLK0.5); also elsewhere on the board
MADDR0: RN1905.7 (R2.2); also elsewhere on the board
MADDR1: RN1905.8 (R1.2); also elsewhere on the board
MADDR2: RN1904.5 (R4.2); also elsewhere on the board
MADDR3: RN1904.6 (R3.2); also elsewhere on the board
MADDR4: RN1904.7 (R2.2); also elsewhere on the board
MADDR5: RN1904.8 (R1.2); also elsewhere on the board
MADDR6: RN1903.5 (R4.2); also elsewhere on the board
MADDR7: RN1903.6 (R3.2); also elsewhere on the board
MADDR8: RN1903.7 (R2.2); also elsewhere on the board
MADDR9: RN1903.8 (R1.2); also elsewhere on the board
MCU_BLANK: U400.140 (~BLANK); also elsewhere on the board
MCU_CMPCS: U400.139 (~CMPCS); also elsewhere on the board
MCU_DCYC: U400.138 (~DCYC); also elsewhere on the board
MCU_LATCH: U400.131 (LATCH); also elsewhere on the board
MCU_RDAT: U400.130 (~RDAT); also elsewhere on the board
MCU_SLOAD: U400.106 (~SLOAD); also elsewhere on the board
MCU_WDAT: U400.129 (~WDAT); also elsewhere on the board
N6850: U400.48 (6850); also elsewhere on the board
unnamed: J1901.1, U400.7 (~ROM0)
unnamed: J1901.3, U400.8 (~ROM1)
unnamed: J1901.11, U400.12 (~ROM5)
unnamed: J1901.13, U400.13 (~ROM6)
RDY: U400.135 (~RDY); also elsewhere on the board
RXW: U400.70 (R/~W); also elsewhere on the board
SHIFTER_16MHZ: U400.2 (CLK16); also elsewhere on the board
SHIFTER_SREQ: U400.107 (SREQ); also elsewhere on the board
SNDCS: U400.19 (SNDCS); also elsewhere on the board
SNDIR: U400.18 (SNDIR); also elsewhere on the board
VSYNC: U400.142 (~VSYNC); also elsewhere on the board
XAS: U400.67 (~AS); also elsewhere on the board
XBGK: U400.26 (~BGACK); also elsewhere on the board
XBLTBG: U400.28 (~BGI); also elsewhere on the board
XBLTINT: U400.60 (~BINT); also elsewhere on the board
XBUTTON: U400.103 (~BUTTON); also elsewhere on the board
XCAS0H: RN1901.7 (R2.2); also elsewhere on the board
XCAS0L: RN1901.6 (R3.2); also elsewhere on the board
XCAS1H: RN1902.7 (R2.2); also elsewhere on the board
XCAS1L: RN1902.6 (R3.2); also elsewhere on the board
XDISKINT: U400.17 (~DISKINT); also elsewhere on the board
XDTACK: U400.71 (~DTACK); also elsewhere on the board
XFCS: U400.136 (~FCS); also elsewhere on the board
XHDINT: R421.2, U400.15 (~HDINT); also elsewhere on the board
XIACK: U400.83 (~IACK); also elsewhere on the board
XIPL0: U400.33 (~IPL0); also elsewhere on the board
XIPL1: U400.34 (~IPL1); also elsewhere on the board
XIPL2: U400.35 (~IPL2); also elsewhere on the board
XJOYRH: U400.99 (~JOYRH); also elsewhere on the board
XJOYRL: U400.100 (~JOYRL); also elsewhere on the board
XJOYWE: U400.101 (~JOYWE); also elsewhere on the board
XLDS: U400.69 (~LDS); also elsewhere on the board
XMFPCS: U400.92 (~MFPCS); also elsewhere on the board
XMFPINT: U400.93 (~MFPINT); also elsewhere on the board
XPAD0X: U400.94 (~PAD0X); also elsewhere on the board
XPAD0Y: U400.95 (~PAD0Y); also elsewhere on the board
XPAD1X: U400.96 (~PAD1X); also elsewhere on the board
XPAD1Y: U400.97 (~PAD1Y); also elsewhere on the board
XPADRST: U400.98 (~PADRST); also elsewhere on the board
XPEN: U400.137 (~PEN); also elsewhere on the board
XRAS0: RN1901.8 (R1.2); also elsewhere on the board
XRAS1: RN1902.8 (R1.2); also elsewhere on the board
XRESET: U400.66 (~RESET); also elsewhere on the board
XROM2: J1901.5, U400.9 (~ROM2); also elsewhere on the board
XROM3: J1901.7, U400.10 (~ROM3); also elsewhere on the board
XROM4: J1901.9, U400.11 (~ROM4); also elsewhere on the board
XSINT: U400.105 (~SINT); also elsewhere on the board
XUDS: U400.68 (~UDS); also elsewhere on the board
XVMA: U400.24 (~VMA); also elsewhere on the board
XVPA: U400.25 (~VPA); also elsewhere on the board
XWE: RN1902.5 (R4.2); also elsewhere on the board

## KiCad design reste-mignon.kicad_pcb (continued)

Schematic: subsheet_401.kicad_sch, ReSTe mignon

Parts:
C412, C413: 0.1uF; C_1206_3216Metric_Pad1.33x1.80mm_HandSolder
H2001, H2002, H2003, H2004: M2.5; MountingHole_2.7mm_M2.5_clear_10mm
J2001: For RGB2HDMI; PinHeader_2x10_P2.54mm_Vertical
R411, R416, R422: 12K; R_1206_3216Metric_Pad1.30x1.75mm_HandSolder
R412, R417, R424: 1K5; R_1206_3216Metric_Pad1.30x1.75mm_HandSolder
R414, R418, R426: 3K; R_1206_3216Metric_Pad1.30x1.75mm_HandSolder
R415, R419, R428: 6K2; R_1206_3216Metric_Pad1.30x1.75mm_HandSolder
R430: 1K; R_1206_3216Metric_Pad1.30x1.75mm_HandSolder
U401: STE_GSTSHIFTER_PHY; PLCC-84_THT-Socket

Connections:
/U401 — GST Shifter/b0: J2001.5, R415.2, U401.49 (B0)
/U401 — GST Shifter/b1: J2001.6, R414.2, U401.48 (B1)
/U401 — GST Shifter/b2: J2001.7, R412.2, U401.47 (B2)
/U401 — GST Shifter/b3: J2001.8, R411.2, U401.46 (B3)
/U401 — GST Shifter/g0: J2001.9, R419.2, U401.45 (G0)
/U401 — GST Shifter/g1: J2001.10, R418.2, U401.44 (G1)
/U401 — GST Shifter/g2: J2001.11, R417.2, U401.43 (G2)
/U401 — GST Shifter/g3: J2001.12, R416.2, U401.42 (G3)
/U401 — GST Shifter/mono: J2001.3, J2001.4, R430.2, U401.50 (MONO)
/U401 — GST Shifter/r0: J2001.13, R428.2, U401.41 (R0)
/U401 — GST Shifter/r1: J2001.14, R426.2, U401.40 (R1)
/U401 — GST Shifter/r2: J2001.15, R424.2, U401.39 (R2)
/U401 — GST Shifter/r3: J2001.16, R422.2, U401.38 (R3)
DATA0: U401.78 (D0); also elsewhere on the board
DATA1: U401.79 (D1); also elsewhere on the board
DATA2: U401.80 (D2); also elsewhere on the board
DATA3: U401.81 (D3); also elsewhere on the board
DATA4: U401.82 (D4); also elsewhere on the board
DATA5: U401.83 (D5); also elsewhere on the board
DATA6: U401.84 (D6); also elsewhere on the board
DATA7: U401.1 (D7); also elsewhere on the board
DATA8: U401.2 (D8); also elsewhere on the board
DATA9: U401.3 (D9); also elsewhere on the board
DATA10: U401.4 (D10); also elsewhere on the board
DATA11: U401.5 (D11); also elsewhere on the board
DATA12: U401.6 (D12); also elsewhere on the board
DATA13: U401.7 (D13); also elsewhere on the board
DATA14: U401.8 (D14); also elsewhere on the board
DATA15: U401.9 (D15); also elsewhere on the board
DE: U401.54 (~DE); also elsewhere on the board
FCLK: U401.34 (FCLK); also elsewhere on the board
GND: C412.2, C413.2, J2001.18, J2001.20, U401.73 (LOWP), U401.74 (GND), U401.75 (GND); also elsewhere on the board
HSYNC: J2001.1; also elsewhere on the board
MC: U401.53 (CLK); also elsewhere on the board
MCU_BLANK: U401.55 (~BLANK); also elsewhere on the board
MCU_CMPCS: U401.18 (~CS); also elsewhere on the board
MCU_DCYC: U401.37 (~LOAD); also elsewhere on the board
MCU_LATCH: U401.76 (LATCH); also elsewhere on the board
MCU_RDAT: U401.77 (~RDAT); also elsewhere on the board
MCU_SLOAD: U401.35 (~SLOAD); also elsewhere on the board
MCU_WDAT: U401.72 (~WDAT); also elsewhere on the board
MDATA0: U401.56 (MD0); also elsewhere on the board
MDATA1: U401.57 (MD1); also elsewhere on the board
MDATA2: U401.58 (MD2); also elsewhere on the board
MDATA3: U401.59 (MD3); also elsewhere on the board
MDATA4: U401.60 (MD4); also elsewhere on the board
MDATA5: U401.61 (MD5); also elsewhere on the board
MDATA6: U401.62 (MD6); also elsewhere on the board
MDATA7: U401.63 (MD7); also elsewhere on the board
MDATA8: U401.64 (MD8); also elsewhere on the board
MDATA9: U401.65 (MD9); also elsewhere on the board
MDATA10: U401.66 (MD10); also elsewhere on the board
MDATA11: U401.67 (MD11); also elsewhere on the board
MDATA12: U401.68 (MD12); also elsewhere on the board
MDATA13: U401.69 (MD13); also elsewhere on the board
MDATA14: U401.70 (MD14); also elsewhere on the board
MDATA15: U401.71 (MD15); also elsewhere on the board
MWD: U401.30 (MWD); also elsewhere on the board
MWK: U401.31 (MWK); also elsewhere on the board
RXW: U401.10 (R/~W); also elsewhere on the board
SCLK: U401.33 (SCLK); also elsewhere on the board
SD0: U401.28 (SD0); also elsewhere on the board
SD1: U401.27 (SD1); also elsewhere on the board
SD2: U401.26 (SD2); also elsewhere on the board
SD3: U401.25 (SD3); also elsewhere on the board
SD4: U401.24 (SD4); also elsewhere on the board
SD5: U401.23 (SD5); also elsewhere on the board
SD6: U401.22 (SD6); also elsewhere on the board
SHIFTER_16MHZ: U401.52 (CLK16); also elsewhere on the board
SHIFTER_BLUE: R411.1, R412.1, R414.1, R415.1; also elsewhere on the board
SHIFTER_GREEN: R416.1, R417.1, R418.1, R419.1; also elsewhere on the board
SHIFTER_MONO: R430.1; also elsewhere on the board
SHIFTER_RED: R422.1, R424.1, R426.1, R428.1; also elsewhere on the board
SHIFTER_SD7: U401.21 (SD7); also elsewhere on the board
SHIFTER_SREQ: U401.36 (SREQ); also elsewhere on the board
VSYNC: J2001.2; also elsewhere on the board
XLD: U401.19 (~LD); also elsewhere on the board
XMWE: U401.29 (~MWE); also elsewhere on the board
XRD: U401.20 (~RD); also elsewhere on the board

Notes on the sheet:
Inverted by U211
Master Clock from U405

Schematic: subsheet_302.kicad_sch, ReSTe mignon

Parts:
C304, C305: 0.1uF; C_1206_3216Metric_Pad1.33x1.80mm_HandSolder
J302: Internal FDD Power; Molex_KK-254_AE-6410-04A_1x04_P2.54mm_Vertical
J303: Internal FDD Port; IDC-Header_2x17_P2.54mm_Vertical
J304: DIN-14S — External FDD Port; socket-din-14
J1701: Jumpers; PinHeader_2x02_P2.54mm_Vertical
R302, R1701: 1K; R_1206_3216Metric_Pad1.30x1.75mm_HandSolder
R307: 220; R_1206_3216Metric_Pad1.30x1.75mm_HandSolder
RN1701, RN1702, RN1704: 1K ×4; R_Array_Convex_4x0603
RN1703: 47 ×4; R_Array_Convex_4x0603
U301: WD1772_FLOPPY_DISK_CONTROLLER_AND_FORMATTER_PHY; DIP-28_W15.24mm_LongPads
U305: 7406_PHY; DIP-14_W7.62mm_LongPads
W300, W301: SW_SPDT; PinHeader_1x03_P2.54mm_Vertical

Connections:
+12V: J302.4; also elsewhere on the board
/U301 — WD1772 and port/DRV_DOIN: J303.18, J304.9, RN1703.1 (R1.1)
/U301 — WD1772 and port/DRV_MON: J303.16, J304.8, R1701.2, U305.10 (5Y)
/U301 — WD1772 and port/DRV_STEP: J303.20, J304.10, RN1703.2 (R2.1)
/U301 — WD1772 and port/DRV_WDATA: J303.22, J304.11, RN1703.3 (R3.1)
/U301 — WD1772 and port/DRV_WGATE: J303.24, J304.12, RN1703.4 (R4.1)
/U301 — WD1772 and port/dirc: U301.17 (DIRC), U305.9 (4A)
/U301 — WD1772 and port/ip: J303.8, J304.4, RN1701.2 (R2.1), U301.24 (~IP)
/U301 — WD1772 and port/mo: U301.20 (MO), U305.11 (5A)
/U301 — WD1772 and port/not_dirc: RN1703.8 (R1.2), RN1704.1 (R1.1), U305.8 (4Y)
/U301 — WD1772 and port/not_step: RN1703.7 (R2.2), RN1704.2 (R2.1), U305.6 (3Y)
/U301 — WD1772 and port/not_wd: RN1703.6 (R3.2), RN1704.3 (R3.1), U305.4 (2Y)
/U301 — WD1772 and port/not_wg: RN1703.5 (R4.2), RN1704.4 (R4.1), U305.2 (1Y)
/U301 — WD1772 and port/rd: J303.30, J304.1, R307.2, U301.19 (~RD)
/U301 — WD1772 and port/step: U301.16 (STEP), U305.5 (3A)
/U301 — WD1772 and port/tr00: J303.26, J304.13, RN1701.3 (R3.1), U301.23 (~TR00)
/U301 — WD1772 and port/wd: U301.22 (WD), U305.3 (2A)
/U301 — WD1772 and port/wg: U301.21 (WG), U305.1 (1A)
/U301 — WD1772 and port/wprt: J303.28, J304.14, RN1701.1 (R1.1), U301.25 (~WPRT)
ACSI_19_HDRQ: RN1702.1 (R1.1), U305.13 (6A); also elsewhere on the board
CADDR1: U301.3 (A0); also elsewhere on the board
CADDR2: U301.4 (A1); also elsewhere on the board
CDATA0: U301.5 (DAL0); also elsewhere on the board
CDATA1: U301.6 (DAL1); also elsewhere on the board
CDATA2: U301.7 (DAL2); also elsewhere on the board
CDATA3: U301.8 (DAL3); also elsewhere on the board
CDATA4: U301.9 (DAL4); also elsewhere on the board
CDATA5: U301.10 (DAL5); also elsewhere on the board
CDATA6: U301.11 (DAL6); also elsewhere on the board
CDATA7: U301.12 (DAL7); also elsewhere on the board
D0SEL: J303.10, W301.1 (A); also elsewhere on the board
D1SEL: J303.12, W300.1 (A), W301.3 (C); also elsewhere on the board
DMA_FDCS: U301.1 (~CS); also elsewhere on the board
DMA_FDRQ: U301.27 (DRQ); also elsewhere on the board
DMA_HDRQ: RN1702.2 (R2.1), U305.12 (6Y); also elsewhere on the board
DMA_RW: U301.2 (R/~W); also elsewhere on the board
FDINT: U301.28 (INTRQ); also elsewhere on the board
GND: C304.2, C305.2, J302.2, J302.3, J303.1, J303.3, J303.5, J303.7, J303.9, J303.11, J303.13, J303.15, J303.17, J303.19, J303.21, J303.23, J303.25, J303.27, J303.29, J303.31, J303.33, J304.3, J304.7, J304.SH (Shield), U301.14 (GND), U301.26 (~DDEN), U305.7 (GND); also elsewhere on the board
unnamed: J304.5, W301.2 (B)
unnamed: J304.6, W300.2 (B)
unnamed: J1701.1, R1701.1
unnamed: J1701.3, RN1704.5 (R4.2), RN1704.6 (R3.2), RN1704.7 (R2.2), RN1704.8 (R1.2)
unnamed: R302.1, W300.3 (C)
S0SEL: J303.32, J304.2; also elsewhere on the board
SCLK: U301.18 (CLK); also elsewhere on the board
XRESET: U301.13 (~MR); also elsewhere on the board

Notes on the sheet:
Factory setting : VCC
Factory setting : D1SEL
see https://www.exxoshost.co.uk/forum/viewtopic.php?f=17&t=1395

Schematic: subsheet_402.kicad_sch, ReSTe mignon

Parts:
C411, C414, C2101: 0.1uF; C_1206_3216Metric_Pad1.33x1.80mm_HandSolder
C2102: 1uF; C_1206_3216Metric_Pad1.33x1.80mm_HandSolder
CP416, CP2101: 47uF; C_Radial_D6.3mm_H11.0mm_P2.50mm
FB401, FB402: Ferrite Bead; L_1206_3216Metric_Pad1.22x1.90mm_HandSolder
J400: DIN-13S — Video Port; socket-din-13
Q400, Q401, Q402, Q403: MMBT3904; SOT-23
R406, R413, R429, R440: 1K; R_1206_3216Metric_Pad1.30x1.75mm_HandSolder
R407, R420, R432: 75; R_1206_3216Metric_Pad1.30x1.75mm_HandSolder
R408, R423, R433: 2K; R_1206_3216Metric_Pad1.30x1.75mm_HandSolder
R409, R425, R434: 150; R_1206_3216Metric_Pad1.30x1.75mm_HandSolder
R431: 1K2; R_1206_3216Metric_Pad1.30x1.75mm_HandSolder
R435, R437: 33; R_1206_3216Metric_Pad1.30x1.75mm_HandSolder
R438: 27; R_1206_3216Metric_Pad1.30x1.75mm_HandSolder
R441: 100; R_1206_3216Metric_Pad1.30x1.75mm_HandSolder
R472: 4K7; R_1206_3216Metric_Pad1.30x1.75mm_HandSolder
U405: 74S257_PHY; DIP-16_W7.62mm_LongPads

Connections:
32MHZ: U405.3 (B1); also elsewhere on the board
+12V: R431.2; also elsewhere on the board
/J400 — Video Port/fvcc1: C411.1, C2102.1, CP2101.1, FB401.2, Q400.3 (C), Q401.3 (C), Q402.3 (C), R406.1, R413.1, R429.1
/J400 — Video Port/fvcc2: C414.1, FB402.2, Q403.3 (C)
/J400 — Video Port/genlock: J400.3, R472.2, U405.1 (SELECT)
/J400 — Video Port/vid4: J400.4, U405.2 (A1), U405.6 (B2)
/J400 — Video Port/vid6_green: J400.6, R420.1
/J400 — Video Port/vid7_red: J400.7, R407.1
/J400 — Video Port/vid10_blue: J400.10, R432.1
/J400 — Video Port/vid11_mono: J400.11, R438.1
AUDIO: CP416.1; also elsewhere on the board
AUDIOI: J400.5; also elsewhere on the board
COMPOSITE_OR_CSYNC: J400.2; also elsewhere on the board
GND: C411.2, C414.2, C2101.2, C2102.2, CP2101.2, J400.13, J400.SH (Shield), R408.2, R409.2, R423.2, R425.2, R433.2, R434.2, R440.2, R441.2, U405.8 (GND), U405.10 (B3), U405.11 (A3), U405.13 (B4), U405.14 (A4), U405.15 (~CONTROL); also elsewhere on the board
HSYNC: R437.2; also elsewhere on the board
MC: U405.4 (Y1); also elsewhere on the board
MONOMON: U405.7 (Y2); also elsewhere on the board
unnamed: CP416.2, J400.1
unnamed: J400.8, R431.1
unnamed: J400.9, R437.1
unnamed: J400.12, R435.1
unnamed: Q400.1 (E), R407.2, R409.1
unnamed: Q401.1 (E), R420.2, R425.1
unnamed: Q402.1 (E), R432.2, R434.1
unnamed: Q403.1 (E), R438.2, R441.1
SHIFTER_BLUE: Q402.2 (B), R429.2, R433.1; also elsewhere on the board
SHIFTER_GREEN: Q401.2 (B), R413.2, R423.1; also elsewhere on the board
SHIFTER_MONO: Q403.2 (B), R440.1; also elsewhere on the board
SHIFTER_RED: Q400.2 (B), R406.2, R408.1; also elsewhere on the board
VSYNC: R435.2; also elsewhere on the board

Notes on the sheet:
It may also be a 74F257
Video ghosting fix : A 47uF low ESR electrolytic capacitor and a 1uF ceramic capacitor in parallel of C411 in parallel of C411. see https://www.exxoshost.co.uk/atari/last/VIDEOFIX/index.htm
Genlock is active low. -> When asserted (low), vid4 is the external video clock of the genlock, and sent as the main clock MC to the shifter ; MONOMON is forced to high (color display). -> When negated (high), the 32MHz clock is sent as the main clock MC to the shifter ; vid4 is the detection of mo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

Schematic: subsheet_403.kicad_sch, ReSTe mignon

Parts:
D401, D402: 1N914; D_SOD-123F
FB410: Ferrite Bead; L_1206_3216Metric_Pad1.22x1.90mm_HandSolder
Q405: MMBT3904; SOT-23
R473: 10K; R_1206_3216Metric_Pad1.30x1.75mm_HandSolder
R474: 100; R_1206_3216Metric_Pad1.30x1.75mm_HandSolder
R475: 150; R_1206_3216Metric_Pad1.30x1.75mm_HandSolder

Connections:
COMPOSITE_OR_CSYNC: R474.1; also elsewhere on the board
GND: R475.2; also elsewhere on the board
HSYNC: D401.1 (K); also elsewhere on the board
unnamed: D401.2 (A), D402.2 (A), Q405.2 (B), R473.2
unnamed: FB410.2, Q405.3 (C), R473.1
unnamed: Q405.1 (E), R474.2, R475.1
VSYNC: D402.1 (K); also elsewhere on the board

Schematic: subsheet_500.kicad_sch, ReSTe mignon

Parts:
C526, C532, C539, C548: 800pF; C_1206_3216Metric_Pad1.33x1.80mm_HandSolder
C527, C533, C540, C549: 0.01uF; C_1206_3216Metric_Pad1.33x1.80mm_HandSolder
C554, C555: 0.1uF; C_1206_3216Metric_Pad1.33x1.80mm_HandSolder
FB500, FB501, FB502, FB503, FB508: Ferrite Bead; L_1206_3216Metric_Pad1.22x1.90mm_HandSolder
J500: DM-15S — JOY0; DSUB-15-HD_Female_Horizontal_P2.29x1.98mm_EdgePinOffset8.35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
J501: DM-15S — JOY1; DSUB-15-HD_Female_Horizontal_P2.29x1.98mm_EdgePinOffset8.35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
R518, R521, R528, R535: 1M; R_1206_3216Metric_Pad1.30x1.75mm_HandSolder
R519, R523, R529, R536: 470; R_1206_3216Metric_Pad1.30x1.75mm_HandSolder
U513, U514: LM556_DUAL_TIMER_PHY; DIP-14_W7.62mm_LongPads

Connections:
/J500 J501 — Gamepad ports/j0_5: C532.1, R523.2, U513.12 (2THRESHOLD), U513.13 (2DISCHARGE)
/J500 J501 — Gamepad ports/j0_15: C526.1, R519.2, U513.1 (1DISCHARGE), U513.2 (1THRESHOLD)
/J500 J501 — Gamepad ports/j1_5: C539.1, R529.2, U514.1 (1DISCHARGE), U514.2 (1THRESHOLD)
/J500 J501 — Gamepad ports/j1_15: C548.1, R536.2, U514.12 (2THRESHOLD), U514.13 (2DISCHARGE)
GND: C526.2, C527.2, C532.2, C533.1, C539.2, C540.2, C548.2, C549.2, C554.2, C555.2, J500.9, J500.SH (Shield), J501.9, J501.SH (Shield), U513.7 (GND), U514.7 (GND); also elsewhere on the board
JOY0_1: J500.1; also elsewhere on the board
JOY0_2: J500.2; also elsewhere on the board
JOY0_3: J500.3; also elsewhere on the board
JOY0_4: J500.4; also elsewhere on the board
JOY0_10: J500.10; also elsewhere on the board
JOY0_11: J500.11; also elsewhere on the board
JOY0_12: J500.12; also elsewhere on the board
JOY0_13: J500.13; also elsewhere on the board
JOY0_14: J500.14; also elsewhere on the board
JOY1_1: J501.1; also elsewhere on the board
JOY1_2: J501.2; also elsewhere on the board
JOY1_3: J501.3; also elsewhere on the board
JOY1_4: J501.4; also elsewhere on the board
JOY1_6: J501.6; also elsewhere on the board
JOY1_10: J501.10; also elsewhere on the board
JOY1_11: J501.11; also elsewhere on the board
JOY1_12: J501.12; also elsewhere on the board
JOY1_13: J501.13; also elsewhere on the board
JOY1_14: J501.14; also elsewhere on the board
unnamed: C527.1, U513.3 (1CTLVLT)
unnamed: C533.2, U513.11 (2CTLVLT)
unnamed: C540.1, U514.3 (1CTLVLT)
unnamed: C549.1, U514.11 (2CTLVLT)
unnamed: FB500.1, J500.5
unnamed: FB500.2, R518.2, R519.1
unnamed: FB501.1, J500.15
unnamed: FB501.2, R521.2, R523.1
unnamed: FB502.1, J501.5
unnamed: FB502.2, R528.2, R529.1
unnamed: FB503.1, J501.15
unnamed: FB503.2, R535.2, R536.1
unnamed: FB508.1, J500.6
XPAD0X: U513.5 (1OUTPUT); also elsewhere on the board
XPAD0Y: U513.9 (2OUTPUT); also elsewhere on the board
XPAD1X: U514.5 (1OUTPUT); also elsewhere on the board
XPAD1Y: U514.9 (2OUTPUT); also elsewhere on the board
XPADRST: U513.6 (1TRIGGER), U513.8 (2TRIGGER), U514.6 (1TRIGGER), U514.8 (2TRIGGER); also elsewhere on the board
XPEN: FB508.2; also elsewhere on the board

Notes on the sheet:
Note : I swapped R518 and R521, as well as R519 and R523, to match what I have on my motherboard.

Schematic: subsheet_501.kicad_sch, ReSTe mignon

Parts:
C550, C551, C552, C553: 0.1uF; C_1206_3216Metric_Pad1.33x1.80mm_HandSolder
RN2401, RN2402, RN2403, RN2404, RN2405, RN2406: 4K7 ×4; R_Array_Convex_4x0603
U509, U510, U512: 74LS244_PHY; DIP-20_W7.62mm_LongPads
U511: 74LS373_PHY; DIP-20_W7.62mm_LongPads

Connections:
/U509~~U512 — Gamepad control/pull_500_2: RN2401.1 (R1.1), U509.2 (1A1)
/U509~~U512 — Gamepad control/pull_500_4: RN2401.3 (R3.1), U509.4 (1A2)
/U509~~U512 — Gamepad control/pull_500_6: RN2402.1 (R1.1), U509.6 (1A3)
/U509~~U512 — Gamepad control/pull_500_8: RN2402.3 (R3.1), U509.8 (1A4)
DATA0: U509.3 (2Y4), U510.18 (1Y1), U511.3 (1D); also elsewhere on the board
DATA1: U509.5 (2Y3), U510.16 (1Y2), U511.4 (2D); also elsewhere on the board
DATA2: U509.7 (2Y2), U510.14 (1Y3), U511.7 (3D); also elsewhere on the board
DATA3: U509.9 (2Y1), U510.12 (1Y4), U511.8 (4D); also elsewhere on the board
DATA4: U509.12 (1Y4), U510.9 (2Y1), U511.13 (5D); also elsewhere on the board
DATA5: U509.14 (1Y3), U510.7 (2Y2), U511.14 (6D); also elsewhere on the board
DATA6: U509.16 (1Y2), U510.5 (2Y3), U511.17 (7D); also elsewhere on the board
DATA7: U509.18 (1Y1), U510.3 (2Y4), U511.18 (8D); also elsewhere on the board
DATA8: U512.18 (1Y1); also elsewhere on the board
DATA9: U512.16 (1Y2); also elsewhere on the board
DATA10: U512.14 (1Y3); also elsewhere on the board
DATA11: U512.12 (1Y4); also elsewhere on the board
DATA12: U512.9 (2Y1); also elsewhere on the board
DATA13: U512.7 (2Y2); also elsewhere on the board
DATA14: U512.5 (2Y3); also elsewhere on the board
DATA15: U512.3 (2Y4); also elsewhere on the board
GND: C550.2, C551.2, C552.2, C553.2, U509.10 (GND), U510.10 (GND), U511.10 (GND), U512.10 (GND); also elsewhere on the board
JOY0_1: RN2404.3 (R3.1), U510.8 (1A4), U511.9 (4Q); also elsewhere on the board
JOY0_2: RN2404.1 (R1.1), U510.6 (1A3), U511.6 (3Q); also elsewhere on the board
JOY0_3: RN2403.3 (R3.1), U510.4 (1A2), U511.5 (2Q); also elsewhere on the board
JOY0_4: RN2403.1 (R1.1), U510.2 (1A1), U511.2 (1Q); also elsewhere on the board
JOY0_10: RN2401.4 (R4.1), U509.15 (2A3); also elsewhere on the board
JOY0_11: RN2406.3 (R3.1), U512.8 (1A4); also elsewhere on the board
JOY0_12: RN2406.1 (R1.1), U512.6 (1A3); also elsewhere on the board
JOY0_13: RN2405.3 (R3.1), U512.4 (1A2); also elsewhere on the board
JOY0_14: RN2405.1 (R1.1), U512.2 (1A1); also elsewhere on the board
JOY1_1: RN2403.2 (R2.1), U510.17 (2A4), U511.19 (8Q); also elsewhere on the board
JOY1_2: RN2403.4 (R4.1), U510.15 (2A3), U511.16 (7Q); also elsewhere on the board
JOY1_3: RN2404.2 (R2.1), U510.13 (2A2), U511.15 (6Q); also elsewhere on the board
JOY1_4: RN2404.4 (R4.1), U510.11 (2A1), U511.12 (5Q); also elsewhere on the board
JOY1_6: RN2402.2 (R2.1), U509.13 (2A2); also elsewhere on the board
JOY1_10: RN2402.4 (R4.1), U509.11 (2A1); also elsewhere on the board
JOY1_11: RN2405.2 (R2.1), U512.17 (2A4); also elsewhere on the board
JOY1_12: RN2405.4 (R4.1), U512.15 (2A3); also elsewhere on the board
JOY1_13: RN2406.2 (R2.1), U512.13 (2A2); also elsewhere on the board
JOY1_14: RN2406.4 (R4.1), U512.11 (2A1); also elsewhere on the board
JOYWL: U511.11 (C); also elsewhere on the board
XBUTTON: U509.1 (~1G), U509.19 (~2G); also elsewhere on the board
XJOYRH: U512.1 (~1G), U512.19 (~2G); also elsewhere on the board
XJOYRL: U510.1 (~1G), U510.19 (~2G); also elsewhere on the board
XJOYWE: U511.1 (~OC); also elsewhere on the board
XPEN: RN2401.2 (R2.1), U509.17 (2A4); also elsewhere on the board

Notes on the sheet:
JOY1_11 to JOY1_14 are in reversed order, to match the wiring on my motherboard.
D4 to D7 are in reversed order, to match the wiring on my motherboard.

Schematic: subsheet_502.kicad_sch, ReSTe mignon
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

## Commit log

2021-12-06 Removed T-filters
    [subsheet_200.sch, subsheet_201.sch, subsheet_202.sch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]
2021-12-08 Added DIP-64 CPU port extension
    [subsheet_100.sch]
2021-12-09 removed the external blitter
    [subsheet_100.sch, subsheet_101.sch]
2021-12-10 Resolves #1 : Use 4-resistor packs wherever it is possible
    [subsheet_100.sch, subsheet_200.sch, subsheet_301.sch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]
2021-12-21 annotate resistor networks and mark unused pins as unconnected
    [subsheet_100.sch, subsheet_200.sch, subsheet_301.sch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]
2021-12-21 Resolves #10 : Remove the C103
    [subsheet_105.sch]
2021-12-21 Resolves #6 : Apply the reset fix
    [subsheet_104.sch]
2021-12-21 Resolves #5 : Apply the fix for the video ghosting
    [subsheet_402.sch]
2022-01-10 Resolves #7 : Assign SMD footprints to resistors pack
    [subsheet_100.sch, subsheet_200.sch, subsheet_301.sch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]
2022-01-11 Resolves #11 : Use the reference 'FB?' for the ferrite beads
    [subsheet_103.sch, subsheet_402.sch, subsheet_403.sch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]
2022-01-11 Resolves #12 : Use the reference 'CP?' for polarized capacitors
    [subsheet_103.sch, subsheet_104.sch, subsheet_105.sch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]
2022-02-09 Resolves #2 : apply the pull-up fix to data and address bus
    [subsheet_100.sch]
2022-02-09 Resolves #3 : Apply the DMA Pull up fix on databus
    [subsheet_300.sch, subsheet_302.sch]
2022-02-10 Resolves #4 : Apply the 1772 pull-up fix
    [subsheet_302.sch]
2022-02-15 Resolves #18 : Apply the LMC mixer fix
    [subsheet_504.sch]
2022-02-15 rename files as 'reste-mignon'
    [reste-mignon.sch, subsheet_100.sch, subsheet_101.sch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]
2022-02-16 Resolves #13 : assign 1206 hand-solder footprints to resistors
    [subsheet_100.sch, subsheet_104.sch, subsheet_200.sch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]
2022-02-16 Resolves #8 : Assign 1206 hand-solder footprints to non polarized capacitors
    [subsheet_100.sch, subsheet_102.sch, subsheet_103.sch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]
2022-03-16 Resolves #20 : Replace polarized capacitors CP101 and CP536 by unpolarized ones
    [subsheet_104.sch, subsheet_504.sch]
2022-03-16 Resolves #9 : Assign radial THT footprints to polarized capacitors
    [subsheet_103.sch, subsheet_104.sch, subsheet_105.sch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]
2022-03-16 Resolves #14 : assign smd footprints for ferrite beads
    [subsheet_103.sch, subsheet_402.sch, subsheet_403.sch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]
2022-04-01 Resolves #16 : assign smd footprints to diodes
    [subsheet_104.sch, subsheet_200.sch, subsheet_205.sch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]
2022-04-01 Resolves #17 : assign smd footprints to transistors
    [subsheet_402.sch, subsheet_403.sch, subsheet_503.sch]
2022-04-01 Resolves #21 : Change Q400 to Q405 from 2N3904 to MMBT3904
    [subsheet_402.sch, subsheet_403.sch]
2022-04-01 Resolves #22 : Change Q500 from LM78L82 to UA78L08 -- add bypass capacitor on input
    [subsheet_503.sch]
2022-06-02 Resolves #15 : assign smd footprints to the inductors
    [subsheet_205.sch]
2022-06-02 Resolves #23 : Add internal ACSI port
    [subsheet_301.sch]
2022-06-03 Resolves #24 : Add an internal port to make easier to plug a RGB2HDMI
    [subsheet_401.sch]
2022-06-08 Fixes #19 : Reinstate the external blitter for the mark 0 version
    [subsheet_100.sch, subsheet_101.sch]
2022-06-08 Prepare the schematics-only release
    [reste-mignon.sch, subsheet_100.sch, subsheet_101.sch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]
2022-06-08 Fixes #28 : [BUG] Incomplete restoration of the blitter
    [subsheet_100.sch]
2022-06-08 Prepare next release (previous one was aborted because of #28)
    [reste-mignon.sch, subsheet_100.sch, subsheet_101.sch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]
2022-06-23 Resolves #33 : Make the WD1772 pull-up fix optionnal
    [subsheet_302.sch]
2022-06-23 Rework the page design : the project url is in a comment, update the date
    [reste-mignon.sch, subsheet_100.sch, subsheet_101.sch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]
2022-07-10 fixed footprint for DIP-64 socket : 900 mils wide, not 600 mils
    [subsheet_100.sch]
2022-07-13 Resolves #31 : Provision mounting holes of the mother board to a chassis
    [subsheet_105.sch]
2022-07-13 Resolves #34 : Provision mounting holes for the Raspberry PI Zero (RGB2HDMI mod)
    [subsheet_401.sch]
2022-07-13 Resolves #32 : Provision mounting hole for the 'dop' series of usb-c power delivery adapter
    [subsheet_105.sch]
2022-07-13 Resolves #35 : [mk0] allow to choose between the legacy reset circuit and a supervisory circuit
    [reste-mignon.sch, subsheet_100.sch, subsheet_101.sch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]
2022-07-14 PCB : provisionnal dimensions and areas
    [reste-mignon.kicad_pcb]
2022-07-14 Resolves #36 : Add a RJ11 Keyboard connector
    [subsheet_201.sch]
2022-07-14 modified target size to B4
    [reste-mignon.kicad_pcb]
2022-07-14 change wrong connector RJ11 (no shield), and missing pin header J1001
    [subsheet_201.sch, subsheet_302.sch]
2022-07-14 Successfully placed all the component inside a B4 surface
    [reste-mignon.kicad_pcb]
2022-07-14 define edges
    [reste-mignon.kicad_pcb]
2022-07-14 change footprint to sockets, adjust cartridge + midi ports, external copper pours
    [subsheet_100.sch, subsheet_300.sch]
2022-07-15 add internal layer to make a 4-layer pcb
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2022-07-15 working on MIDI ports, swap connections to resistor network
    [subsheet_200.sch]
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2022-09-23 pcb session -- ven. 23 sept. 2022 23:18:20 CEST
2022-09-29 pcb session -- jeu. 29 sept. 2022 11:56:23 CEST
2022-09-29 pcb session -- jeu. 29 sept. 2022 12:30:19 CEST
2022-09-29 pcb session -- jeu. 29 sept. 2022 13:13:36 CEST
2022-09-29 pcb session -- jeu. 29 sept. 2022 19:04:06 CEST
2022-09-29 pcb session -- jeu. 29 sept. 2022 23:38:31 CEST
    [subsheet_100.sch, subsheet_101.sch]
2022-09-30 pcb session -- ven. 30 sept. 2022 07:13:44 CEST
2022-10-22 update custom footprint : radial inductor tht, diam 15mm, pitch 5mm
2022-10-22 Resolves #39 : [mk0] Select THT power inductors for L203-L208
    [subsheet_205.sch]
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2022-10-24 Fixes #40 : Q500, revert to TO-92 package and alternatives references
    [subsheet_503.sch]
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2022-10-25 pcb session 2022-10-25T07:12:15+02:00 : provision space for RGB2HDMI
2022-10-25 added missing bypass capacitor for U405
    [subsheet_402.sch]
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2022-10-28 Resolves #37 : [mk0] Add a breakout connector for serial and parallel signal
    [subsheet_202.sch]
2022-10-28 Resolves #38 : [mk0] add a breakout connector for the MCU ROM[0..6]
    [subsheet_400.sch]
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2023-01-21 MIGRATION TO KICAD 6 !
    [reste-mignon.kicad_sch, subsheet_100.kicad_sch, subsheet_101.kicad_sch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]
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2023-01-21 pcb session 2023-01-21T22:41:51+01:00
    [subsheet_100.kicad_sch, subsheet_101.kicad_sch, subsheet_102.kicad_sch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]
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2023-01-23 add gnd/vcc symbol to start replacing local labels
    [reste-mignon.kicad_sch, subsheet_100.kicad_sch, subsheet_101.kicad_sch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]
2023-01-23 connect vcc/gnd, pp 28,29
    [reste-mignon.kicad_sch, subsheet_100.kicad_sch, subsheet_101.kicad_sch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]
2023-01-23 replace symbol Device:CP1 by Device:C_Polarized_US
    [reste-mignon.kicad_sch, subsheet_103.kicad_sch, subsheet_104.kicad_sch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]
2023-11-20 convert to Kicad 7
    [reste-mignon.kicad_sch, reste-mignon.sch, subsheet_100.kicad_sch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]
2023-11-20 cleanstep : remove kicad 5 files
    [subsheet_100.sch, subsheet_101.sch, subsheet_102.sch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]
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2024-06-11 complete specification of CPU + blitter extension connector
2024-06-13 added new library of symbols to have CPU connector A and B
2024-06-16 cpu and blitter extension port -- specify how it is wired on mainboard and extensions
2024-06-20 Fixes extension port cpu Connector B -- pinout
2024-06-20 ad-hoc symbols for extension port cpu and blitter connectors
2024-06-20 create project
    [reste-mignon-extension-cpu-68k-plcc68.kicad_pcb, reste-mignon-extension-cpu-68k-plcc68.kicad_sch]
2024-06-20 Setup metadata, starting schematic
    [reste-mignon-extension-cpu-68k-plcc68.kicad_sch]
2024-06-21 done main wiring, remaining pull-ups
    [reste-mignon-extension-cpu-68k-plcc68.kicad_sch]
2024-06-22 done schematic
    [reste-mignon-extension-cpu-68k-plcc68.kicad_sch]
2024-06-22 done footprint association, DRC
    [reste-mignon-extension-cpu-68k-plcc68.kicad_sch]
2024-06-22 pcb session -- laying out component -- fixed footprint associations
    [reste-mignon-extension-cpu-68k-plcc68.kicad_pcb, reste-mignon-extension-cpu-68k-plcc68.kicad_sch]
2024-06-22 pcb session -- change cpu orientation for easier routing
    [reste-mignon-extension-cpu-68k-plcc68.kicad_pcb]
2024-06-22 pcb session -- start wiring
    [reste-mignon-extension-cpu-68k-plcc68.kicad_pcb]
2024-06-23 pcb session -- start pull-ups, adjust pull-up mapping of RN1 for ease of routing
    [reste-mignon-extension-cpu-68k-plcc68.kicad_pcb, reste-mignon-extension-cpu-68k-plcc68.kicad_sch]
2024-06-23 pcb session -- continue pull-ups, done a1-a12
    [reste-mignon-extension-cpu-68k-plcc68.kicad_pcb, reste-mignon-extension-cpu-68k-plcc68.kicad_sch]
2024-06-23 pcb session -- switch to 4 layers, spread vias to avoid cuts in ground plane
    [reste-mignon-extension-cpu-68k-plcc68.kicad_pcb]
2024-06-23 pcb session -- done the address bus a1~a23
    [reste-mignon-extension-cpu-68k-plcc68.kicad_pcb]
2024-06-23 switch RN5 and RN6 to ease routing
    [reste-mignon-extension-cpu-68k-plcc68.kicad_pcb, reste-mignon-extension-cpu-68k-plcc68.kicad_sch]
2024-06-23 pcb session -- adjust constraints to pass drc, silkscreen -- start using free angles
    [reste-mignon-extension-cpu-68k-plcc68.kicad_pcb]
2024-06-23 pcb session -- done using free angles -- good enough to order
    [reste-mignon-extension-cpu-68k-plcc68.kicad_pcb]
2024-06-24 pcb session -- adding measurements -- some more free angles
    [reste-mignon-extension-cpu-68k-plcc68.kicad_pcb]
2024-06-24 pcb session -- tweaks angles here and there
    [reste-mignon-extension-cpu-68k-plcc68.kicad_pcb]
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2024-06-26 pcb session -- replicate most marking onto the back silkscreen
    [reste-mignon-extension-cpu-68k-plcc68.kicad_pcb]
2024-06-26 pcb session -- tweak traces again for better regularity, fix copper pour for ground
    [reste-mignon-extension-cpu-68k-plcc68.kicad_pcb]
2024-06-27 prepare release of the extension cpu
    [reste-mignon-extension-cpu-68k-plcc68.kicad_pcb, reste-mignon-extension-cpu-68k-plcc68.kicad_sch]
2024-06-28 fix drill file generation
